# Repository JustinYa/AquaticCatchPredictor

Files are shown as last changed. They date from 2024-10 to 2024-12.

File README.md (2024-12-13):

# Abstract

AquaticCatchPredictor is a predictive system designed to enhance fishing efficiency by leveraging environmental data and machine learning. It analyzes key factors such as temperature, pressure, water activity, and geographic location to determine the best fishing spots and predict fish activity. The system integrates real-time weather data and decision tree models to provide actionable insights, helping anglers make informed decisions. Its user-centric design focuses on accuracy, usability, and adaptability to diverse aquatic environments.

# Team

* Zixuan Yang

# Required Submissions  

* [Website](https://justinya.github.io/AquaticCatchPredictor/)
* [Proposal](https://github.com/JustinYa/AquaticCatchPredictor/blob/main/docs/proposal.md)
* [Midterm Checkpoint Presentation Slides](https://github.com/JustinYa/AquaticCatchPredictor/blob/main/docs/midtermPresentation.pdf)
* [Final Presentation Slides](https://docs.google.com/presentation/d/1H-CBQTqb1kGFo9P-xzhdKyaAK2egp4QP/edit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)
* [Final Report](https://github.com/JustinYa/AquaticCatchPredictor/blob/main/docs/report.md)
* [Prediction Mode Demo Video](https://drive.google.com/file/d/1JTeIy1hggbkSafa4Nath8DWK5p9Q1THv/view?usp=sharing)
* [Location Suggestion & Navigation Modes Demo Video](https://drive.google.com/file/d/1JZ9xc8-V4VDqHVV1dyS5ZUOEnqnyqMGk/view?usp=sharing)

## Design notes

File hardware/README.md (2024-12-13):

# Hardware Folder

This folder contains all the hardware-related files for the **Fishing Prediction System**. The files include PCB layouts, electrical schematics, and 3D models for both the central and peripheral device enclosures.

## Contents

### 1. **PCB Layout**
- **`PCB_layout.pdf`**:  
  This file contains the PCB layout used to connect the electronic modules of the central device. It serves as the foundation for integrating all components within the system.

### 2. **Electrical Schematic**
- **`SCH_Schematic.pdf`**:  
  This file provides the complete electrical schematic for the system. It details all the connections between the components, ensuring accurate assembly of the electronic modules.

### 3. **3D Models**
The folder includes `.stl` files for the enclosures of the central and peripheral devices, as well as demo files representing fully assembled devices:

#### Central Device:
- **`centralA.stl`** and **`centralB.stl`**:  
  These are the 3D models for the **enclosure of the central device**.
- **`central_device_demo.stl`**:  
  This file represents the **fully assembled central device**, showcasing how the components fit together.

#### Peripheral Device:
- **`peripheralA.stl`** and **`peripheralB.stl`**:  
  These are the 3D models for the **enclosure of the peripheral device**.
- **`peripheral_demo.stl`**:  
  This file represents the **fully assembled peripheral device**, providing a complete view of the final design.

## Usage Instructions
1. **PCB Layout**:  
   Use `PCB_layout.pdf` as a reference for creating the circuit board to connect the central device's electronic modules.
2. **Electrical Schematic**:  
   Refer to `SCH_Schematic.pdf` to ensure all components are correctly connected during assembly.
3. **3D Models**:  
   - Load the `.stl` files into a 3D modeling or printing tool to visualize or manufacture the enclosures.  
   - Use the `*_demo.stl` files to understand the final appearance of the fully assembled devices.

## Notes
- The `PCB_layout.pdf` and `SCH_Schematic.pdf` files are crucial for ensuring proper hardware functionality.  
- The `.stl` files allow you to fabricate the physical enclosures for the devices and understand the assembly process.

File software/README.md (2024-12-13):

# Software Folder

This folder contains all the necessary software files for the **Fishing Prediction System**. It includes Arduino IDE sketches for the central and peripheral devices, as well as a Python script for training the decision tree model.

## Contents

### 1. **Arduino Files**
These `.ino` files are used to program the central and peripheral devices using the **Arduino IDE**:
- **`ble_central.ino`**:  
  The code for the **central device**, handling data collection, Bluetooth communication, and predictions using pre-trained models.
- **`ble_peripheral.ino`**:  
  The code for the **peripheral device**, responsible for gathering environmental data (temperature, pressure, etc.) and transmitting it to the central device via Bluetooth.

### 2. **Python Script**
- **`decision_tree_training.ipynb`**:  
  This Python notebook is used to train the **decision tree model**. It processes collected data, trains the model, and exports the decision tree rules for integration into the Arduino sketches.

## Usage Instructions
1. **Arduino Sketches**:  
   - Open `ble_central.ino` and `ble_peripheral.ino` in the Arduino IDE.
   - Upload the respective code to the central and peripheral devices to enable system functionality.
2. **Python Script**:  
   - Run `decision_tree_training.ipynb` in a Jupyter Notebook environment to train the decision tree model.
   - Export the trained model logic and incorporate it into the central device's Arduino code for predictions.

## Notes
- Ensure all required libraries for Arduino IDE are installed before uploading the sketches.
- The Python script requires standard machine learning libraries like `scikit-learn` for training the decision tree model.

For further assistance, refer to the main repository README or contact the project team.

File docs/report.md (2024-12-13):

# Table of Contents
* Abstract
* [Introduction](#1-introduction)
* [Related Work](#2-related-work)
* [Technical Approach](#3-technical-approach)
* [Evaluation and Results](#4-evaluation-and-results)
* [Discussion and Conclusions](#5-discussion-and-conclusions)
* [Demo Links](#6-demo-links)
* [References](#7-references)

# Abstract

The AquaticCatchPredictor project utilizes Machine Learning techniques to analyze fishing data, including GPS location, temperature, air pressure, and water activity. By collecting real-time environmental data, the system predicts catch rates under current fishing conditions and provides on-site recommendations to enhance fishing success. This approach aims to assist anglers in making informed decisions based on environmental factors, thereby improving their catch rates. The integration of machine learning ensures that predictions adapt to varying conditions, making the AquaticCatchPredictor a valuable tool for recreational and professional fishing alike.

# 1. Introduction

# 1. Introduction

## 1.1. Motivation & Objective

Fishing can be an enjoyable and rewarding activity, but it is not without its frustrations. One memorable experience involved using a fishing app that predicted excellent fish activity, prompting a fishing trip with friends. Unfortunately, not a single fish was caught that day, which highlighted the limitations of existing fishing prediction tools. This experience inspired the idea for a more reliable and data-driven solution. Both recreational and competitive anglers could benefit from such a system, as it would help them save time, reduce wasted effort, and improve their overall fishing success.

The primary objective of this project is to develop a portable device that predicts fish activity and recommends optimal fishing spots. This device will integrate environmental data such as temperature, pressure, and weather conditions to analyze fish behavior effectively. Additionally, the system will provide real-time insights using GPS and live weather updates, ensuring anglers have the most accurate information. By incorporating decision tree algorithms, this solution will improve prediction accuracy, reduce uncertainty, and create a more effective fishing experience.

## 1.2. State of the Art & Its Limitations

Currently available fishing apps rely heavily on general weather data and historical trends to provide predictions. While these tools offer a basic level of assistance, they have several limitations. For example, they often lack real-time data integration, which makes it challenging to adapt to changing environmental conditions. Additionally, these apps do not provide location-specific accuracy, which is crucial for anglers seeking reliable predictions for specific fishing spots. Personalized recommendations based on individual preferences or fishing goals are also absent in most existing solutions.

These limitations lead to inconsistent performance, which diminishes user trust and effectiveness. This project aims to address these shortcomings by providing a data-driven, accurate, and personalized solution tailored to the unique needs of anglers.

## 1.3. Novelty & Rationale

This project offers several unique features that set it apart from current fishing prediction tools. First, the predictions are based on scientifically collected data, ensuring high reliability and accuracy. The device also includes offline functionality, enabling it to operate independently of internet access by utilizing onboard sensors and pre-trained models. Furthermore, decision tree algorithms are employed to deliver precise predictions about fish activity, providing a significant improvement over generalized or heuristic approaches. These innovations make the system an effective tool for improving fishing outcomes in diverse conditions.

## 1.4. Potential Impact

This fishing prediction system provides anglers with accurate, location-specific insights, improving catch rates and reducing wasted effort. For competitive anglers, it offers a strategic advantage through real-time data and decision tree algorithms. Its offline functionality enables use in remote areas, while promoting sustainable fishing by minimizing environmental impact. With strong potential for commercial applications, the system addresses key gaps in current fishing technologies and enhances the overall fishing experience.

## 1.5. Challenges

Collecting a robust and comprehensive dataset for training the model within the constraints of limited time and resources is a significant challenge. To ensure the model's accuracy and generalizability, the dataset must include diverse fishing scenarios, incorporating varying skill levels of anglers, from beginners to experts. Additionally, it is essential to gather data from multiple locations within the same waterbody, covering a wide range of environmental conditions such as temperature, pressure, and water activity. These variations are critical for capturing the complex factors that influence fish behavior. Achieving this level of diversity in data collection requires extensive planning, coordination, and effort, making it one of the most demanding aspects of the project.

## 1.6. Required Skills and Resources

Successfully completing this project requires a combination of skills and hardware resources:

### Skills
- **Sensor Integration**: Proficiency in working with sensors such as thermometers, barometers, and IMUs to collect accurate environmental data.
- **Bluetooth Communication**: Knowledge of Bluetooth protocols to enable seamless data transfer between devices.
- **Microcontroller Programming**: Familiarity with embedded system programming, particularly for configuring and managing microcontroller operations.
- **PCB Design**: Experience in designing and fabricating printed circuit boards (PCBs) to integrate system components efficiently.
- **3D Modeling**: Ability to create 3D models for designing and manufacturing the device’s enclosure, ensuring durability and ergonomic design.

### Hardware Resources
- **ESP32**: A versatile microcontroller for managing system operations and communication.
- **Arduino Nano 33 BLE**: For low-power processing and Bluetooth communication.
- **0.97-inch OLED Display**: For displaying real-time predictions and system status.
- **Neo-6M GPS Module**: For obtaining accurate location data to improve fishing predictions.

## 1.7. Metrics of Success

The success of the fishing prediction system is evaluated using a combination of accuracy, performance, and efficiency metrics. Prediction accuracy is assessed through Mean Squared Error (MSE), which calculates the average squared difference between predicted and actual values, and Root Mean Squared Error (RMSE), which provides an interpretable error measure in the same units as the target variable. To analyze model performance, Relative Error is used to measure the difference between testing and training MSE as a percentage of the training MSE, highlighting potential overfitting or underfitting. Prediction speed is another key metric, focusing on the time required for the system to compute a prediction, which is critical for real-time applications. Additionally, power efficiency is evaluated by measuring average power consumption in milliwatts (mW) and estimating battery life in hours based on the available power source. These metrics collectively ensure the system's accuracy, responsiveness, and practicality in real-world scenarios.

# 2. Related Work

Fishing apps are widely available on the market and are popular among anglers for their ability to predict fish activity. These apps typically gather environmental data such as temperature, barometric pressure, and wind speed through internet-based weather services. By combining this information with basic fishing heuristics—such as how weather conditions influence fish behavior—they aim to provide users with insights into the best times and locations to fish. However, the reliance on simplistic rules rather than advanced data-driven algorithms often results in limited prediction accuracy and adaptability, particularly in dynamic or less-studied fishing environments.

Most of these applications are designed for use on smartphones, leveraging their convenience and portability. However, they are heavily dependent on an active internet connection to fetch real-time data. This reliance introduces a significant limitation: in remote locations where internet access is unavailable or unreliable, these apps become unusable. Such scenarios are common in rural or wilderness fishing spots, leaving anglers without reliable tools to guide their efforts.

This project seeks to address these limitations by designing a fully offline solution that does not rely on internet connectivity. Instead, it integrates onboard sensors to collect local environmental data and employs advanced machine learning algorithms to provide accurate predictions. By eliminating the need for external data sources, this system ensures functionality in remote areas while offering a higher degree of reliability and precision compared to existing fishing apps. This offline capability not only enhances usability but also makes the system a more practical and versatile tool for anglers in diverse environments.

# 3. Technical Approach

## 3.1. System Architecture

The system is designed with a modular architecture comprising two main components: a peripheral device and a central device. Each component has distinct responsibilities that work in tandem to collect, process, and deliver fishing predictions. The two devices communicate wirelessly via Bluetooth, ensuring efficient data transfer and seamless functionality in real-time.

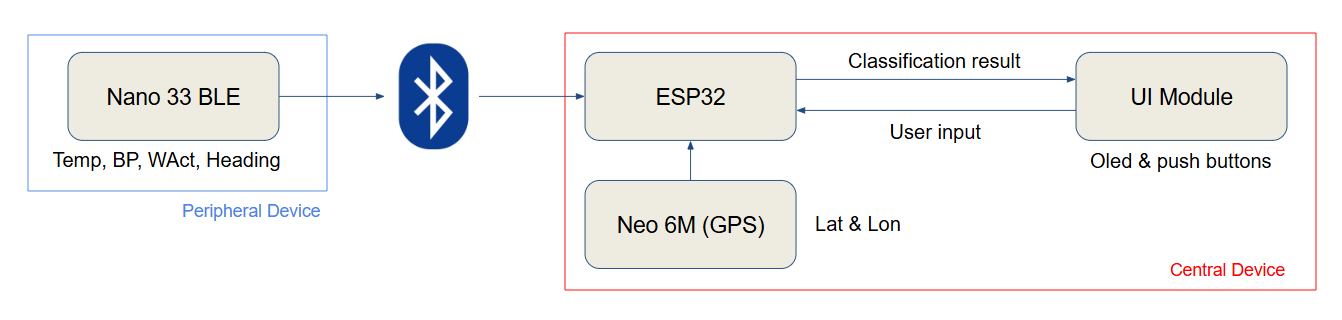
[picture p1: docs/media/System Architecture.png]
System Architecture


The **peripheral device** is built around the Arduino Nano 33 BLE, chosen for its low power consumption and integrated Bluetooth capabilities. Powered by a 500mAh LiPo battery, it is equipped with several onboard sensors to capture environmental data. These include:
- **Water Temperature Sensor**: Measures the temperature of the water.
- **Barometric Pressure Sensor**: Records atmospheric pressure for weather analysis.
- **Inertial Measurement Unit (IMU)**: Detects water surface activity based on motion data.
- **Magnetometer**: Monitors orientation to account for device positioning.

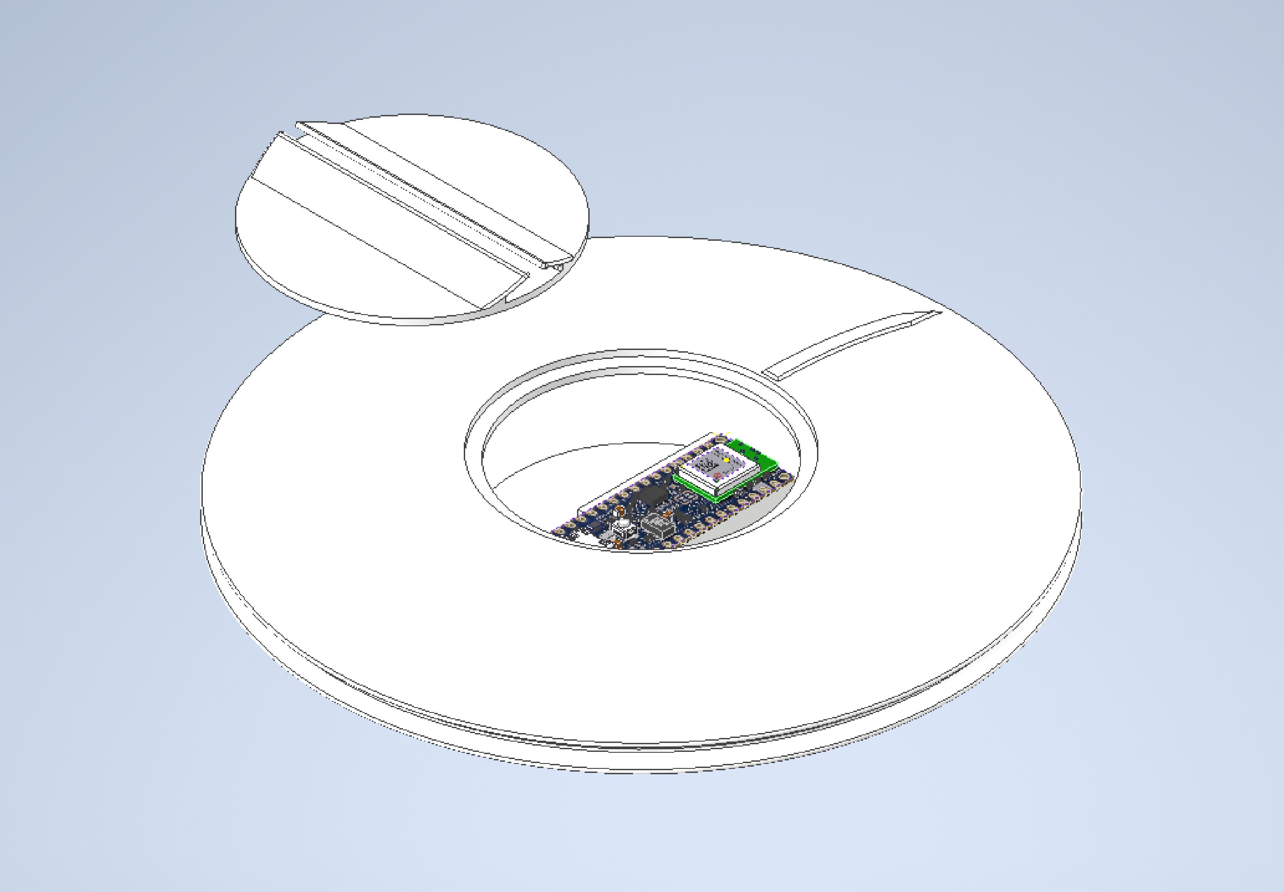
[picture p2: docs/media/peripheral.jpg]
Peripheral Device


The peripheral device collects these data points and transmits them wirelessly to the central device, ensuring that the system can operate effectively even in remote locations.

The **central device**, powered by an ESP32 microcontroller, is the computational hub of the system. It processes the data received from the peripheral device and generates fishing predictions using pre-trained machine learning models. The central device is equipped with:
- A **Neo-6M GPS Module** for obtaining precise location data, critical for tailoring predictions to specific fishing spots.
- An **OLED Display** for presenting fishing recommendations and system status to the user.
- **Push Buttons** to allow for user interaction, such as inputting preferences or navigating the interface.
- A **500mAh LiPo Battery**, providing sufficient power for extended use in outdoor environments.

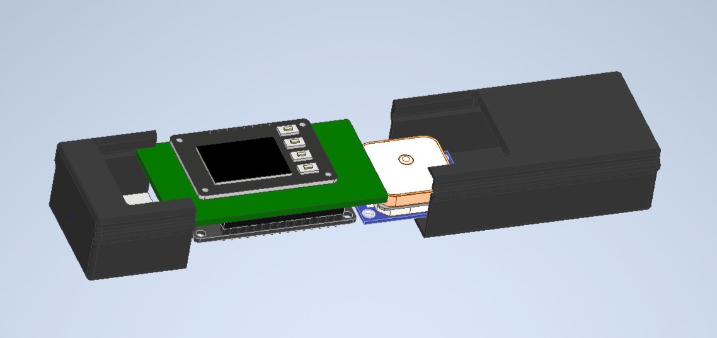
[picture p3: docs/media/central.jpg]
Central Device
 

The communication between the peripheral and central devices relies on Bluetooth, ensuring fast and reliable data transfer without the need for internet connectivity. This modular design allows for flexibility and scalability, with the peripheral device specializing in data collection and the central device handling computation and user interaction. By separating these roles, the system achieves higher efficiency and adaptability, making it suitable for various fishing scenarios and environments.

## 3.2. Data Collection

The data collection process was designed to ensure a comprehensive dataset by incorporating variations in fishing skill levels, locations, environmental conditions, and weather patterns.

### Participants
Three participants with varying fishing expertise—beginner, intermediate, and expert—were selected to contribute to the dataset. This diversity ensures that the collected data reflects a wide range of fishing behaviors and skill levels, which is crucial for building a robust prediction model.

### Locations
Data was collected simultaneously at three distinct spots within the same waterbody. Peripheral devices were connected to the nRF App on smartphones for real-time logging. These spots were chosen to capture diverse environmental conditions, enhancing the dataset’s representativeness.

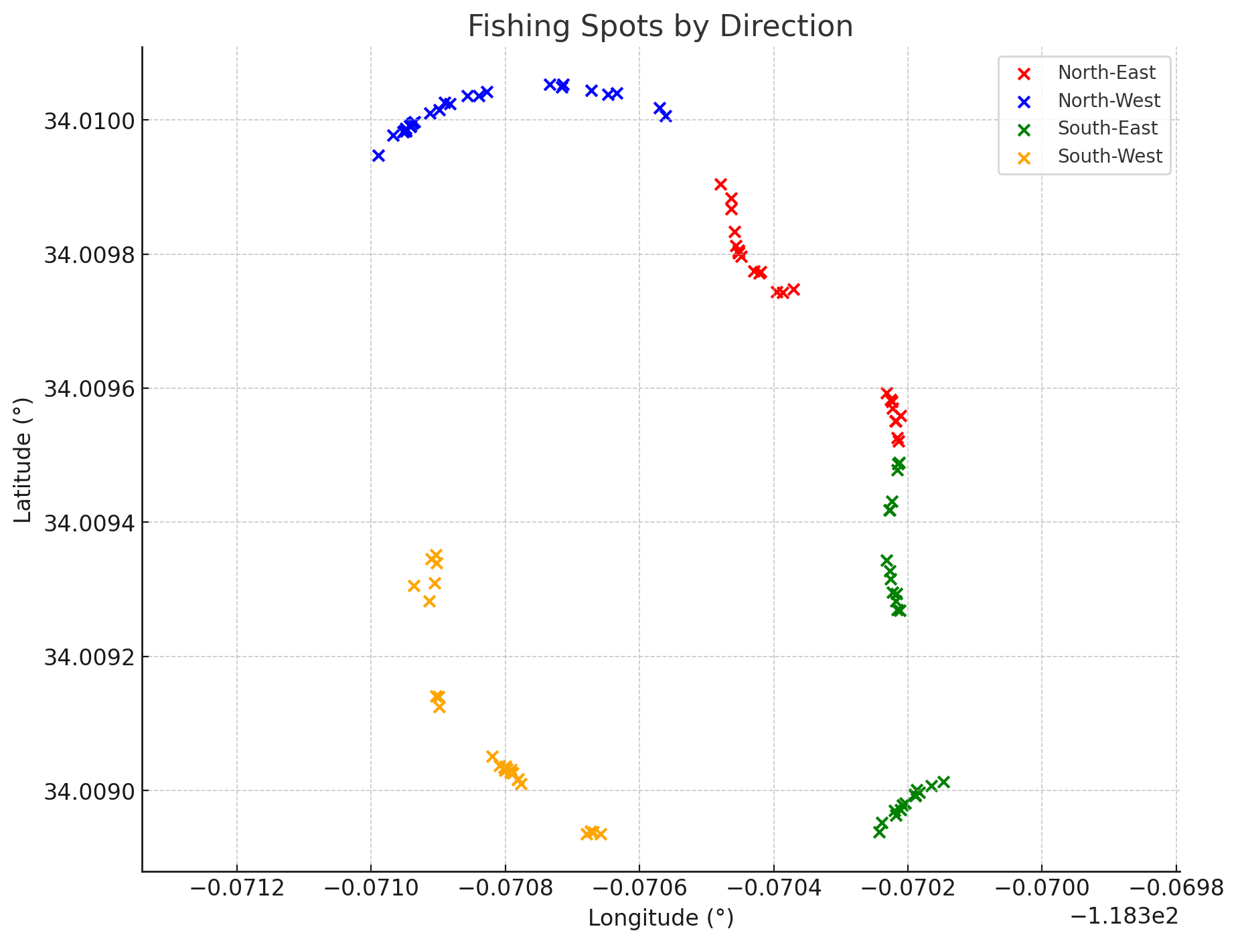
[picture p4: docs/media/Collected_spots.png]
Collected Spots


### Process
Each data collection session lasted 30 minutes, with participants rotating between the three locations every 10 minutes. This rotation ensured that each location included data from all three participants, thereby improving the objectivity and reliability of the dataset. Efforts were made to cover the entire lake during data collection, but certain areas, such as the North-West section, were inaccessible due to obstructions like reeds.

### Duration
Data collection was conducted over six days, with three hours of collection each day. The weather conditions during these six days were carefully distributed: two days were categorized as hot, two as cold, and two as moderate. This distribution allowed the dataset to capture the influence of varying weather conditions on fish behavior. Each day yielded 18 individual data entries, resulting in a total of 108 data points for the entire experiment.

The structured process of data collection, combined with diverse participant expertise, strategically chosen locations, and a variety of weather conditions, ensures that the dataset is comprehensive, reliable, and suitable for training the fishing prediction model.

## 3.3. Data Processing

The data collected during the experiment was processed to create a structured and reliable dataset for analysis and model training. Data from the nRF App was exported and consolidated into an Excel spreadsheet, including variables such as date, latitude, longitude, temperature, pressure, water activity, bite rate, and fishing spot location. The bite rate, calculated by summing the catches from all three participants at each location during a 30-minute session, served as the key target variable for the model. This approach ensured a comprehensive measure of fish activity, accounting for variations in skill levels and environmental conditions. The dataset was thoroughly reviewed for quality, with no missing values identified. However, minor GPS shifts were observed and manually adjusted to maintain accuracy. These steps ensured the dataset's readiness for machine learning applications, forming a solid foundation for reliable fishing predictions.

## 3.4. Model Training

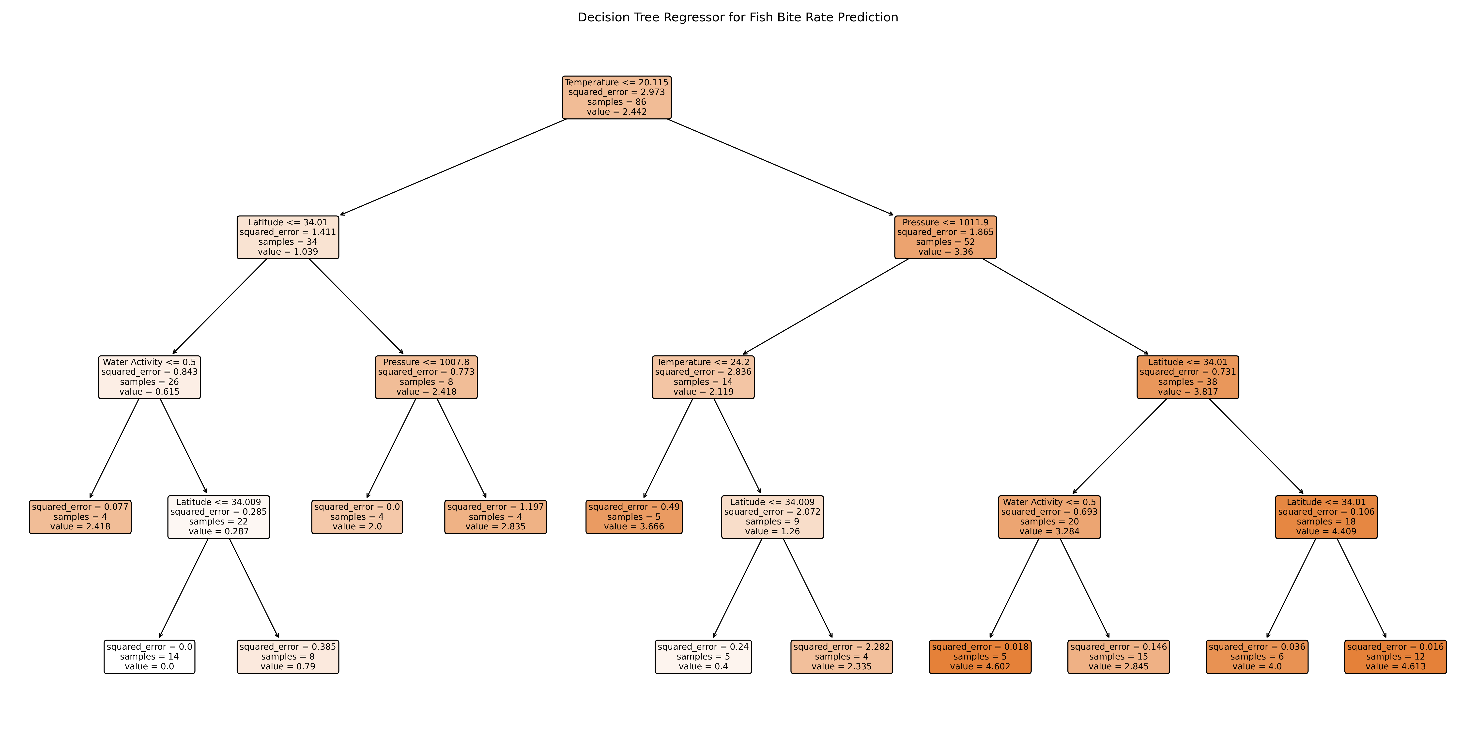
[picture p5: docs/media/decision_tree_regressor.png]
Decision Tree


The prediction model was built using a decision tree regressor implemented in Python. The input features included environmental variables such as temperature, pressure, water surface activity, and geographical location. These variables were selected for their direct impact on fish behavior and bite rates. The dataset was split into training and testing sets using an 80/20 ratio to ensure a balanced evaluation of the model’s performance. The decision tree algorithm was chosen for its interpretability and ability to handle non-linear relationships within the data. 

## 3.5. Model Tuning

During initial training, the decision tree model exhibited signs of overfitting, with the training Mean Squared Error (MSE) being significantly lower than the testing MSE. To address this issue, parameters such as the maximum depth of the tree and the minimum number of samples required at a leaf node were introduced to constrain the model's complexity. The best performance was achieved with a maximum depth of 4 and a minimum of 4 samples per leaf, which balanced the trade-off between accuracy and generalization. This tuning step ensured that the model could make reliable predictions without overfitting to the training data.

# 4. Evaluation and Results

## 4.1. Results

The performance of the fishing prediction system was evaluated across multiple dimensions, including prediction accuracy, processing speed, and power efficiency. These evaluations reflect the system’s suitability for real-world fishing applications and its ability to operate under various constraints.

### Prediction Accuracy
The decision tree model demonstrated reliable predictive performance, achieving the following metrics:
- **Testing MSE**: 0.2498  
- **Training MSE**: 0.2751  
- **Testing RMSE**: 0.4998  
- **Training RMSE**: 0.5245  
- **Relative Error**: 10.12% (difference between Training MSE and Testing MSE)

Model Accuracy Results

The small difference between training and testing MSE indicates that the model has effectively avoided overfitting, maintaining good generalization across unseen data. The RMSE values further provide an interpretable measure of error in the same units as the target variable, confirming the model's accuracy for predicting fish bite rates.

### Feature Importance

The feature importance analysis reveals that **Temperature** is the most significant factor, with an importance score of **0.56**, indicating its dominant role in the model's predictions. Other features like **Latitude** (**0.19**), **Pressure** (**0.13**), and **Water Activity** (**0.12**) also contribute meaningfully, while **Longitude** (**0.00**) has no observable impact. These results suggest that the model is primarily driven by temperature variations, with secondary influences from location and pressure metrics.

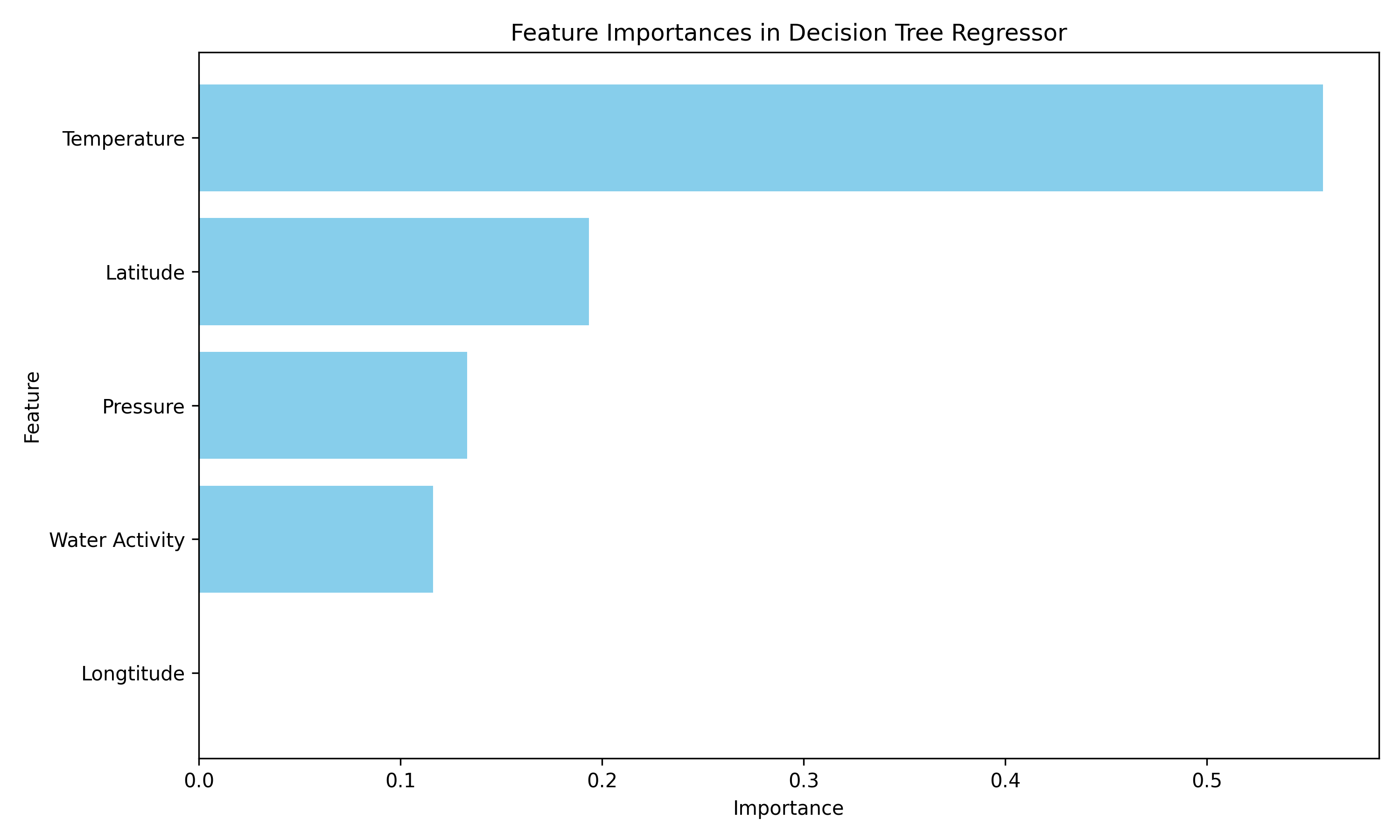
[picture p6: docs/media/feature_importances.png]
Feature Importances


### Processing Speed
The system achieved an average prediction speed of **15 ms** per query, enabling near-instantaneous feedback for users in real-time fishing scenarios. This rapid response ensures that anglers can make timely decisions based on current environmental conditions.

### Power Efficiency
The power efficiency of the system was analyzed for both the central and peripheral devices:

#### Central Device
- **Average Power Consumption**: 408.6 mW  
- **Battery Life**: Approximately 4.77 hours on a 500mAh battery  
- **Memory Usage**: 90%

The central device’s higher power consumption is attributed to its computational workload, which includes processing data, running machine learning models, and managing the user interface. Despite this, the device maintains sufficient battery life for typical fishing trips.

#### Peripheral Device
- **Average Power Consumption**: 70.2 mW  
- **Battery Life**: Approximately 27.76 hours on a 500mAh battery  
- **Memory Usage**: 23%

The peripheral device’s low power consumption and memory usage highlight its role as a dedicated data collection unit, with an extended battery life that ensures uninterrupted operation during long fishing sessions. Combined with the central device’s efficient power management and high computational capability, the results demonstrate a well-balanced system that excels in prediction accuracy, responsiveness, and energy efficiency. The low relative error confirms the reliability and generalization of the model, while the fast prediction speed makes it practical for real-time use. These features collectively ensure prolonged usability in outdoor environments, even under limited power availability, making the system a robust and effective tool for enhancing the fishing experience for both recreational and professional anglers.

## 4.2. Findings

A user study involving five participants provided valuable insights into how the fishing prediction system was used by different groups and its effectiveness under real-world conditions. 

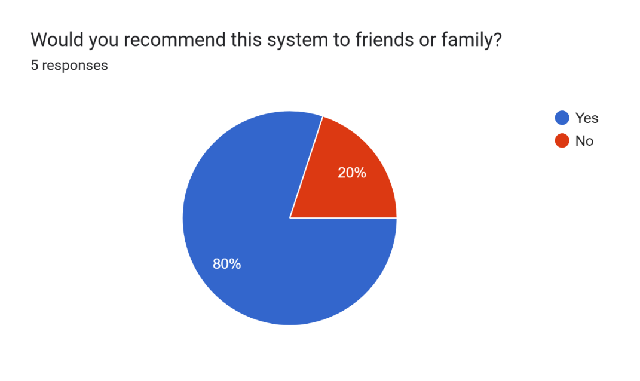
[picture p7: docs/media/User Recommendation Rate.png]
User Recommendation Feedback


### Beginners 
Beginners exhibited a high level of dependence on the system, using it more frequently to guide their fishing efforts. They primarily relied on the system's location recommendations to identify optimal fishing spots, particularly when navigating unfamiliar environments. Despite this reliance, their actual catch rates were generally lower than the system's predictions. This discrepancy can be attributed to two main factors: the participants' lack of fishing experience and the limitations of the training dataset. During data collection, the dataset did not include data from individuals with no fishing experience, leading to a slight mismatch between the model's predictions and the performance of completely inexperienced users. For this group, the system acted as a critical tool to improve their understanding of fishing conditions and strategies, even if their results initially fell short of predictions. 

To address this limitation in the future, a potential improvement could involve adding a **rating functionality** to the system. Users could self-assess and input their fishing skill level, allowing the system to appropriately scale its predictions based on their experience. This feature would enable more personalized and accurate recommendations for users of all skill levels.

### Intermediate and Advanced Users
Intermediate and advanced users demonstrated a different usage pattern, interacting with the system less frequently compared to beginners. These participants showed a high alignment between their actual catch rates and the system's predictions, reflecting their ability to effectively combine personal experience with system insights. For this group, the fish activity predictions were particularly valuable, as they used the system to refine their fishing strategies rather than as a primary guide. The system served as a supplementary tool to enhance their fishing efficiency and decision-making.

The study highlighted the system's ability to cater to a wide range of users. Beginners benefited most from the location recommendations, using the system to gain confidence and improve their results. In contrast, more experienced anglers used the system to enhance their existing skills, demonstrating its adaptability and effectiveness across skill levels. These findings underscore the system’s potential as both a learning aid and a strategic tool for diverse fishing scenarios, with opportunities for future enhancements such as skill-based scaling to improve its accuracy and usability.

# 5. Discussion and Conclusions

## Discussion

### Hardware Improvements
The system’s hardware components are functional but present opportunities for improvement. Replacing the current GPS module with an Adafruit GPS module could lower power consumption and support low-power modes, extending battery life for prolonged use. Additionally, optimizing the device enclosure to make it more compact and portable would enhance user convenience, especially for outdoor activities.

### Data Collection
Expanding the scope of data collection to include more sessions and diverse water bodies would significantly improve the model's accuracy and generalizability. Incorporating data from a wider range of environmental conditions and user experiences, including completely inexperienced anglers, could help address current limitations and refine the system’s predictions.

### Future Features
Future iterations of the system could include additional measurements such as water depth and dissolved oxygen to improve prediction accuracy. Furthermore, integrating a user rating feature would allow individuals to specify their skill level. This feature would enable the system to scale predictions accordingly, providing personalized recommendations tailored to each user’s expertise.

## Conclusions
The fishing prediction system successfully helps both beginners and experienced anglers by providing actionable fishing predictions. Beginners benefit most from location recommendations, frequently using the system as a guide to navigate unfamiliar conditions. Experienced users rely more on fish activity predictions to refine their strategies, using the system as a supplementary tool. 

The decision tree model performs well, achieving low testing errors and accurate predictions under diverse conditions. The system’s real-time prediction capability and low power consumption make it a reliable choice for extended fishing trips. User feedback underscores the system’s value, with 80% of participants expressing a willingness to recommend it to others.

Overall, the system demonstrates its potential to enhance the fishing experience for a wide range of users, while the proposed improvements and features highlight opportunities to further increase its effectiveness and user satisfaction.

# 6. Demo Links

* [Prediction Mode Demo Video](https://drive.google.com/file/d/1JTeIy1hggbkSafa4Nath8DWK5p9Q1THv/view?usp=sharing)
* [Location Suggestion & Navigation Modes Demo Video](https://drive.google.com/file/d/1JZ9xc8-V4VDqHVV1dyS5ZUOEnqnyqMGk/view?usp=sharing)

# 7. References

1. M. Iiyama, K. Zhao, A. Hashimoto, H. Kasahara, and M. Minoh, “Fishing spot prediction by sea temperature pattern learning,” *2018 OCEANS - MTS/IEEE Kobe Techno-Oceans (OTO)*, pp. 1–4, May 2018. doi: [10.1109/oceanskobe.2018.8559299](https://doi.org/10.1109/oceanskobe.2018.8559299)

2. M.-T. Thai, T.-N. Chu-Ha, T.-A. Vo, and T.-H. Do, “An approach to recommend fishing location and forecast fish production by using Big Data Analysis and distributed deep learning,” *2022 RIVF International Conference on Computing and Communication Technologies (RIVF)*, pp. 322–327, Dec. 2022. doi: [10.1109/rivf55975.2022.10013876](https://doi.org/10.1109/rivf55975.2022.10013876)

3. Gauravduttakiit, “Hyperparameter tuning in decision trees,” *Kaggle*, [https://www.kaggle.com/code/gauravduttakiit/hyperparameter-tuning-in-decision-trees](https://www.kaggle.com/code/gauravduttakiit/hyperparameter-tuning-in-decision-trees) (accessed Dec. 12, 2024).

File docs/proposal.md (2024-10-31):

# Proposal for Portable Fishing Prediction System

---

### 1. Motivation & Objective
The primary goal of this project is to increase fishing efficiency by providing anglers with a real-time fishing index based on various environmental factors, including temperature, barometric pressure, water activity, and GPS location. By analyzing these parameters on-site, the system aims to offer more accurate fishing predictions than generic weather-based solutions, ultimately enhancing the fishing experience and success rate.

---

### 2. State of the Art & Its Limitations
Currently, most fishing prediction systems are based on empirical knowledge and some known environmental factors rather than scientific analysis derived from actual data. These systems often fail to accurately capture the specific conditions of the fishing site, such as real-time water activity and localized weather patterns, which can significantly influence fish behavior. Additionally, traditional fishing apps depend on cloud services for data processing and prediction, which presents several limitations. First, they require a stable internet connection, making them unreliable in remote fishing locations with poor or no signal. Second, relying on cloud processing drains phone battery life quickly, which limits usability during extended fishing trips. In contrast, an on-device, low-power sensor system can continuously monitor environmental factors specific to the fishing location. This approach is not only more energy-efficient but also works offline, enhancing both longevity and privacy.

---

### 3. Novelty & Rationale
This project introduces several novel elements to fishing prediction. First, by using localized, real-time data, the system relies on actual data from the fishing site, such as water movement detected by an accelerometer, along with temperature, pressure, and location, to provide a comprehensive fishing index. Second, the system supports offline capability. By utilizing pre-trained machine learning models, it processes data locally, eliminating the need for cloud-based computations and enabling functionality in remote fishing locations without cellular connectivity. Additionally, for pattern recognition, the device uses decision trees or SVM (Support Vector Machines) to analyze patterns from the collected data, allowing it to dynamically identify optimal fishing conditions without requiring constant internet access. Furthermore, this system could be beneficial in competitive fishing events like Bassmaster, where it provides insights into fish activity patterns in specific water areas. By offering data-driven analyses, it has the potential to increase the event's appeal to audiences. This combination of real-time, location-specific analysis with energy-efficient, offline operation sets the device apart from conventional fishing prediction systems.

---

### 4. Potential Impact
The successful implementation of this project could have a significant impact on recreational and competitive fishing. By offering more accurate, real-time predictions, anglers can make informed decisions about where and when to fish, improving their success rate and overall satisfaction. Additionally, with better data on fish activity, anglers can target specific times for fishing, potentially reducing overfishing and promoting sustainable practices. Furthermore, this project demonstrates the potential of TinyML and low-power sensor fusion in outdoor, real-time applications, encouraging further development in portable IoT solutions.

---

### 5. Challenges
This project faces several challenges. First, unlike weather forecasting, fishing prediction requires specific environmental and behavioral data for different fishing locations and times. There is no existing comprehensive database, necessitating the collection of real-world data across various conditions. Second, to ensure the data accurately represents different fishing environments, input is needed from anglers of varied experience levels in multiple geographic and environmental settings. This diversity is crucial to train a model that generalizes well across conditions.

---

### 6. Requirements for Success
The success of this project hinges on several technical skills and hardware components. Key technical skills include proficiency in C++ and Python programming, particularly for embedded systems development. Familiarity with machine learning, especially in model optimization for embedded devices (TinyML), is crucial for achieving efficient, on-device processing. Additionally, 3D modeling skills are needed to design a portable and ergonomic casing for the device. A basic knowledge of fishing is also beneficial for understanding and identifying relevant environmental factors that influence fish activity.

The hardware requirements for this project include a microcontroller, such as the ESP32, to act as the core processing unit. Environmental sensors, specifically for temperature and barometric pressure, will provide real-time data about the fishing conditions. A water activity sensor, like an accelerometer, is essential for detecting movements in the water that may signal fish activity. The system also requires a GPS module for precise location tracking and a portable power source, such as a rechargeable battery, to ensure the device can operate for extended periods in remote locations.

---

### 7. Metrics of Success
The effectiveness of the fishing prediction system will be evaluated through several performance metrics. Prediction accuracy is critical; the system should reliably estimate fish activity based on environmental data. High accuracy will indicate the device’s effectiveness in analyzing real-time conditions. Another important metric is user satisfaction, which will be assessed through a survey with anglers. The survey will evaluate the prediction accuracy, ease of use, and overall utility of the device in real fishing scenarios, providing valuable feedback for further improvements.

---

### 8. Execution Plan
In the **Data Collection Phase**, data will be gathered on temperature, pressure, water movement, and GPS location across various fishing sites using a custom-designed Arduino measurement device. Collaborating with anglers to collect a diverse dataset is crucial to ensure the model’s generalizability and accuracy in different fishing conditions. 

Following data collection, the **Model Training & Optimization** phase will involve training a machine learning model, such as decision trees or SVM, on the collected data to identify patterns in fish activity. Optimization techniques like quantization and pruning will be applied to reduce model size and power requirements, enabling efficient operation on embedded hardware. 

In the **Prototype Development** phase, a prototype will be built that integrates the selected sensors, microcontroller, and power supply. Testing in real-world fishing conditions will allow for refining the device’s sensitivity and accuracy. 

The **Evaluation and Refinement** phase involves multiple rounds of testing and iteration based on performance metrics, user feedback, and battery life optimization. Finally, in the **Deployment & Field Testing** phase, the finalized prototype will be field-tested with a larger user base for additional feedback and adjustments.

---

### 9. Related Work
Though resources on freshwater fishing prediction are limited, insights can be drawn from related research on ocean fishing. For example, studies such as "Fishing Spot Prediction by Sea Temperature Pattern Learning" and "An Approach to Recommend Fishing Location and Forecast Fish Production by Using Big Data Analysis and Distributed Deep Learning" provide valuable methodologies. Although these works primarily utilize data from existing databases, they offer useful experimental frameworks that can guide the approach to data collection and analysis in a freshwater context.

---

### 10. References
- M. Iiyama, K. Zhao, A. Hashimoto, H. Kasahara and M. Minoh, "Fishing Spot Prediction by Sea Temperature Pattern Learning," 2018 OCEANS - MTS/IEEE Kobe Techno-Oceans (OTO), Kobe, Japan, 2018, pp. 1-4, doi: 10.1109/OCEANSKOBE.2018.8559299. keywords: {Ocean temperature;Support vector machines;Training data;Machine learning;Boats;Temperature distribution}.

- M. -T. Thai, T. -N. Chu-Ha, T. -A. Vo and T. -H. Do, "An Approach to Recommend Fishing Location and Forecast Fish Production by Using Big Data Analysis and Distributed Deep Learning," 2022 RIVF International Conference on Computing and Communication Technologies (RIVF), Ho Chi Minh City, Vietnam, 2022, pp. 322-327, doi: 10.1109/RIVF55975.2022.10013876. keywords: {Deep learning;Costs;Time series analysis;Predictive models;Big Data;Fish;Data models;Fishing forecast;Big Data;Time Series;Recommendation System;Distributed Deep Learning}.

---

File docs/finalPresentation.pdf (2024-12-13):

# Aquatic Catch

Predictor.

## Zixuan Yang

Motivation.

### 1. Personal Inspiration:

As an avid fishing enthusiast, I encountered a frustrating experience where a fishing app predicted excellent fish activity, leading me to

invite friends for a fishing trip. Unfortunately, not a single fish was caught that day. This sparked the idea for a more reliable and data-driven

solution.

### 2. Significance:

Who cares?

Recreational and competitive anglers aiming to improve their skills and catch rates.

Why does it matter?

Saves time and resources, creating a more enjoyable and effective fishing experience.

Objectives.

Portable Device: Create a compact system capable of predicting fish activity and recommending optimal fishing spots.

Environmental Analysis: Integrate data from temperature, pressure, and weather conditions to assess fish behavior.

Real-time Insights: Use GPS and live weather updates to identify fishing spots with the highest success potential.

Enhanced Experience: Reduce uncertainty and improve catch rates through data-driven decision-making using decision trees for

prediction.

Related Work.

Existing Solutions: Current fishing apps, offer predictions based on general weather data and

historical trends.

Limitations: These apps often lack real-time data integration, location-specific accuracy, and

personalized recommendations for anglers.

Inconsistent Performance: The variability in prediction accuracy underscores the need for a more

reliable, data-driven solution tailored to individual fishing scenarios.

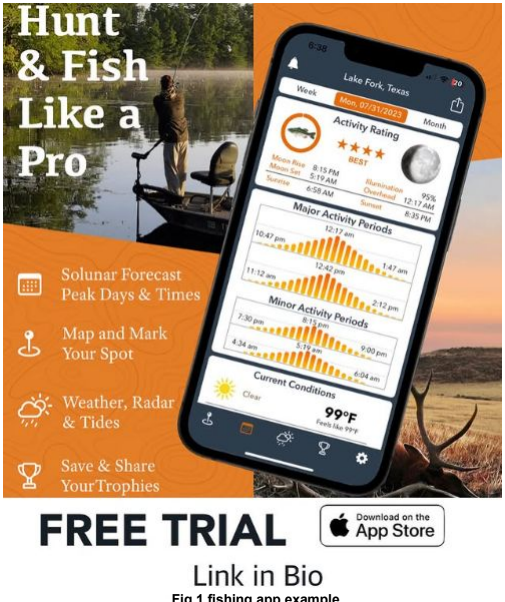
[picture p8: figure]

Fig.1 fishing app example

Novelty.

What's New:

Scientifically Collected Data: Predictions are supported by scientifically collected data, ensuring high reliability and accuracy in results.

Offline Functionality: Operates seamlessly without internet access, using onboard sensors and pre-trained models to provide predictions in

any environment.

Decision Tree Predictions: Utilizes decision tree algorithms for precise fish activity forecasts, providing a significant improvement over

generalized or heuristic methods.

Technical Approach.

The system consists of a peripheral device and a central device, optimized for specific roles:

Peripheral Device:

- Uses the Arduino Nano 33 BLE & 500mah Lipo battery with onboard sensors to collect:
- Water temperature (temperature sensor).
- Atmospheric pressure (barometric sensor).
- Water surface activity (IMU).
- Orientation (magnetometer).
- Sends data to the central device via Bluetooth.

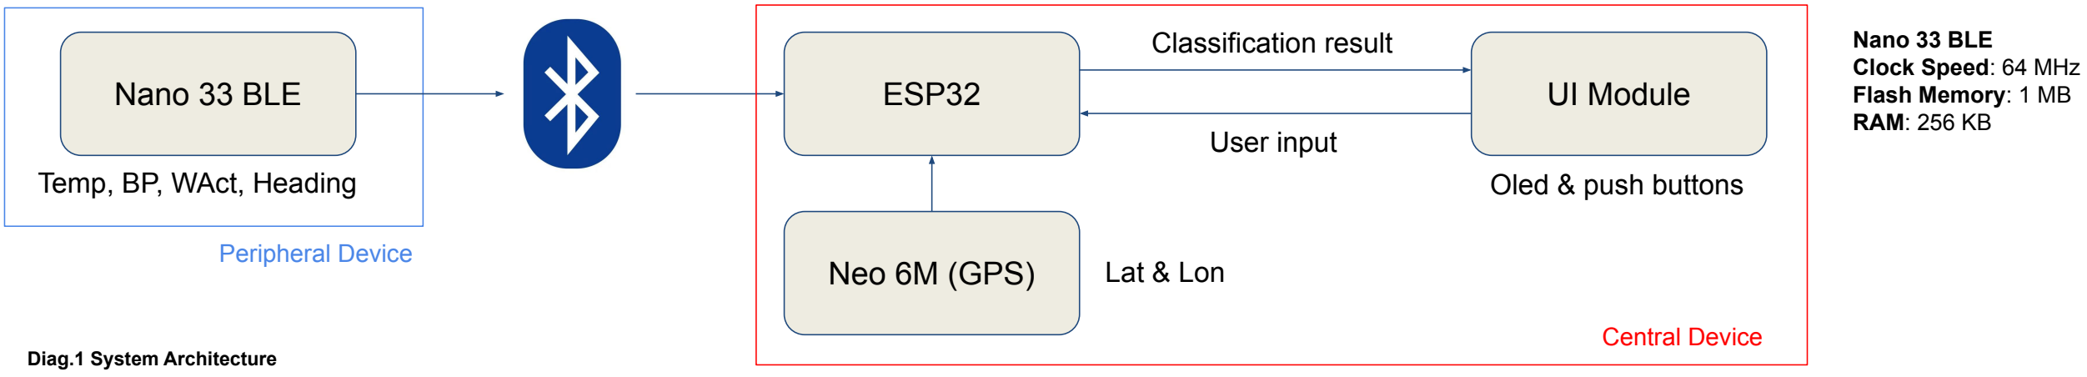
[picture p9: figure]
Nano 33 BLE; ESP32; Neo 6M (GPS); UI Module; Temp, BP, WAct, Heading; Central Device; Peripheral Device; Lat & Lon; Classification result; User input; Oled & push buttons; Diag.1 System Architecture; Nano 33 BLE Clock Speed: 64 MHz Flash Memory: 1 MB RAM: 256 KB

Technical Approach.

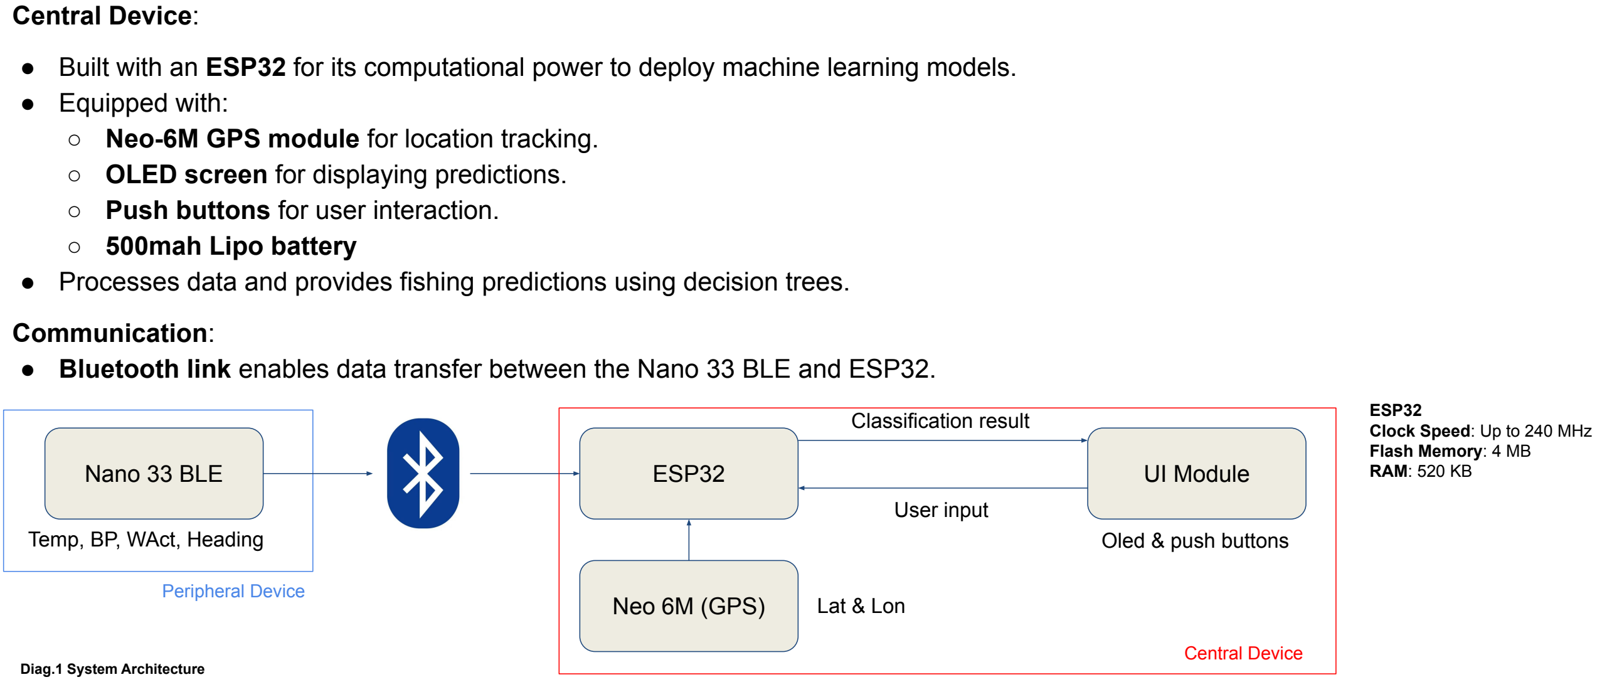
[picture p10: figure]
Neo 6M (GPS); Temp, BP, WAct, Heading; Central Device; Peripheral Device; Lat & Lon; Classification result; User input; Oled & push buttons; Central Device:; ● Equipped with:; ○ Push buttons for user interaction. ○ 500mah Lipo battery; Communication:; Diag.1 System Architecture; ESP32 Clock Speed: Up to 240 MHz

- Built with an ESP32 for its computational power to deploy machine learning models.
- Neo-6M GPS module for location tracking.
- OLED screen for displaying predictions.
- Processes data and provides fishing predictions using decision trees.
- Bluetooth link enables data transfer between the Nano 33 BLE and ESP32.
Nano 33 BLE | ESP32 UI Module | Flash Memory: 4 MB RAM: 520 KB

# Methods. data collection

Participants:

Three individuals with varying fishing skill levels: beginner, intermediate, and expert.

Locations:

Data collected simultaneously at three different spots using peripheral devices connected

to the nRF App on smartphones for logging.

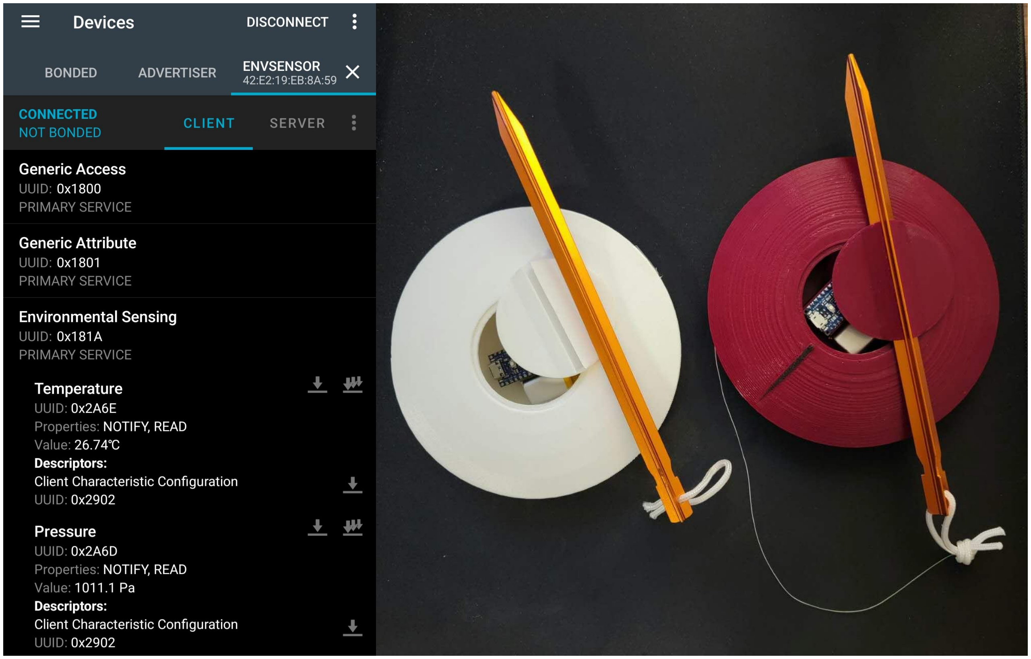
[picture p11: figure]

Fig.2 nRF App | Fig.3 Peripheral Devices (prototype_left)

# Methods. data collection

Process:

- Each session lasts 30 minutes, participants rotate between locations every 10

minutes.

- This ensures that each location has data contributed by all three participants,

enhancing the objectivity and reliability of the dataset.

- During data collection, efforts were made to cover the entire lake; however, a

section in the North-West area was obstructed by reeds, making it inaccessible for

data collection.

Duration:

- Data collected over 6 days, with 3 hours of collection each day.

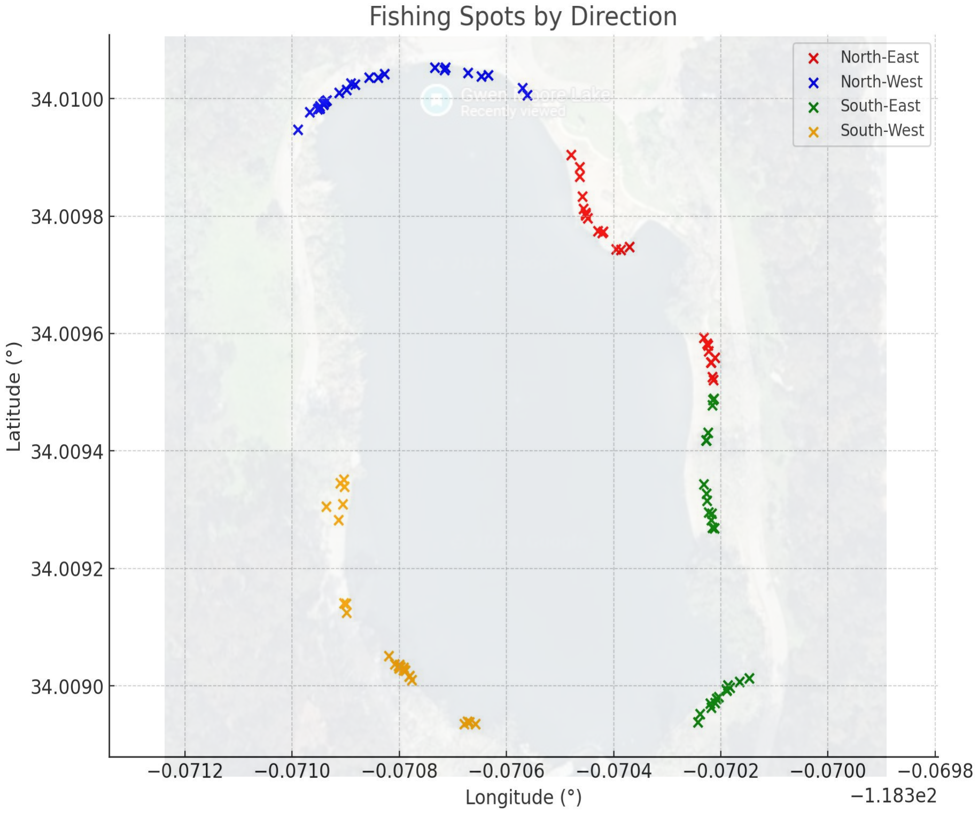
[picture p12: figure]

- Each day yields 18 data entries, totaling 108 data points across the experiment. | Fig.4 Collected Fishing Spots

# Methods. data processing

Data Aggregation:

- Collected data from the nRF App is exported and consolidated into an Excel

spreadsheet for analysis.

Bite Rate Calculation:

- Bite rate is determined by summing the catch data from all three participants at

each location during a 30-minute session.

- This provides a comprehensive measure of fish activity across skill levels at each

spot.

Data Quality:

- No missing values were identified during the data review process.
- GPS data occasionally showed slight shifts, requiring manual adjustments to

ensure accuracy.

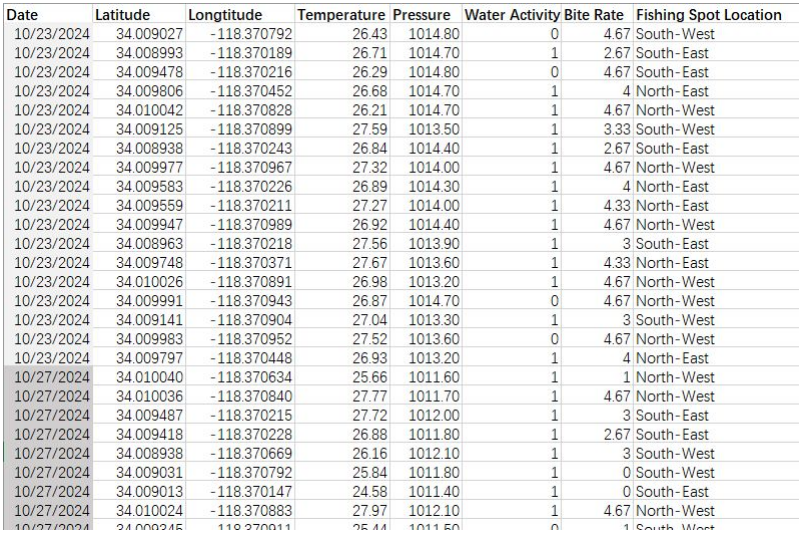
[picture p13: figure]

Fig.5 dataset

# Methods. model training

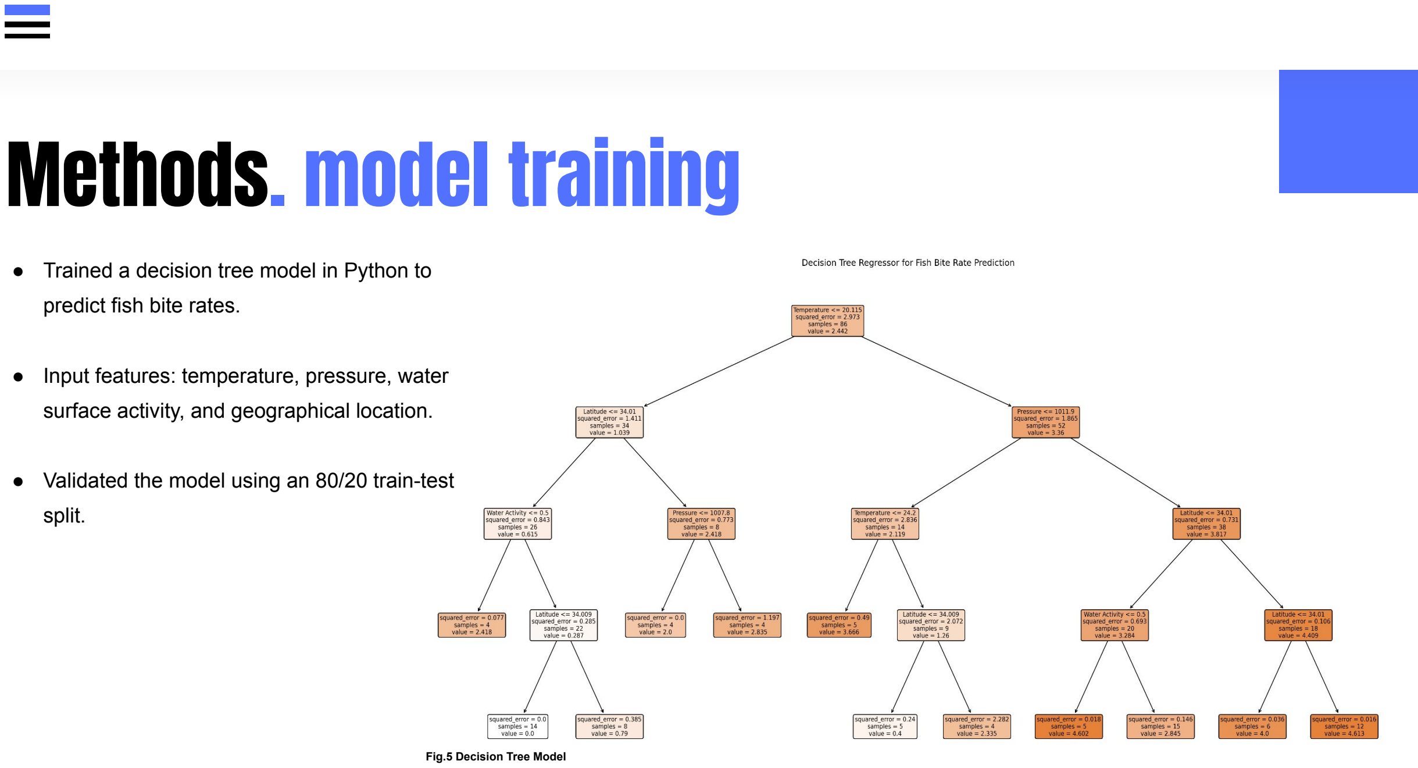
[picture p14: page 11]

- Trained a decision tree model in Python to

predict fish bite rates.

- Input features: temperature, pressure, water

surface activity, and geographical location.

- Validated the model using an 80/20 train-test

split.

Fig.5 Decision Tree Model

# Methods. model tuning

- Directly training the decision tree without constraints results in training MSE being significantly smaller than

testing MSE, indicating overfitting.

- To address this, max depth and min samples leaf parameters are introduced to limit the tree's complexity and

reduce overfitting.

- Achieved best performance with max_depth=4 and min_samples_leaf=4, balancing accuracy and

generalization.

Demo.

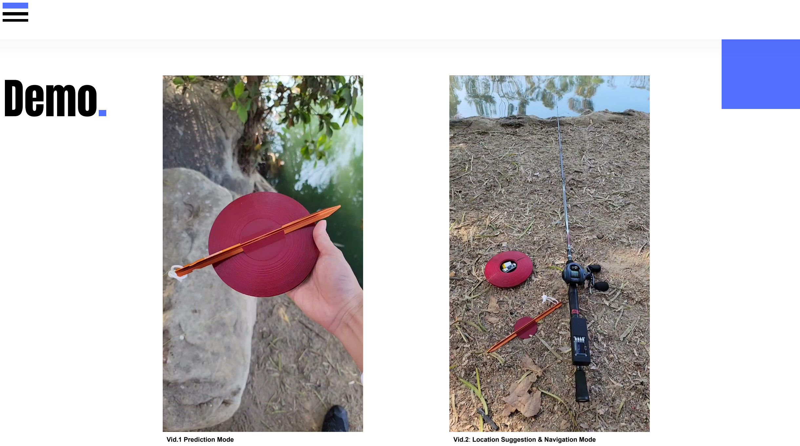
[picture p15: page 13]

Vid.1 Prediction Mode | Vid.2: Location Suggestion & Navigation Mode

# Experimental Evaluation. Metrics

MSE: Evaluates the average squared error between predicted and actual values to

measure accuracy.

RMSE: Square root of MSE, providing an interpretable error in the same units as the

target variable.

Relative Error: Measures the difference between testing and training MSE as a

percentage of the training MSE.

Prediction Speed: Measure the time taken for the system to compute a prediction.

Power Efficiency: Evaluate the system's energy consumption during operation.

- Average power consumption (mW).
- Battery life (hours) on a given power source.

# Experimental Evaluation. Results

Testing MSE: 0.2498 | Training MSE: 0.2751
Testing RMSE: 0.4998 | Training RMSE: 0.5245

Relative Error: 10.12% (Training MSE: 0.2751 vs. Testing MSE: 0.2498)

Average Prediction Speed: 15 ms

Central Device Power Efficiency:

- Average power consumption 408.6 mW.
- Battery life 4.77 hours.

Memory use: 90%

Peripheral Device Power Efficiency:

- Average power consumption 70.2mW.
- Battery life 27.76 hours.

Memory use: 23%

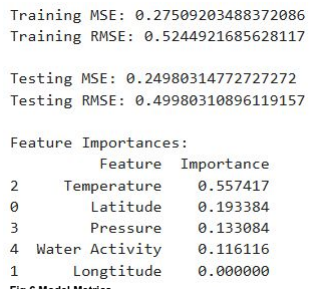
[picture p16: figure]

Fig.6 Model Metrics

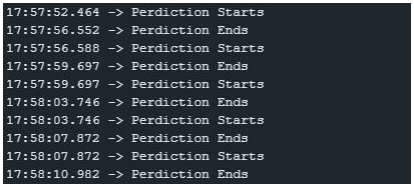
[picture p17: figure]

Fig.7 Serial Monitor output of prediction time

# Experimental Evaluation. Finding

Beginners without any experiences:

- Show a higher level of dependence on the system and use it more frequently.
- Their actual catch rates are generally lower than the system's predictions due to lack of experience.
- Rely heavily on fishing location recommendations for guidance.

Intermediate and Advanced Users:

- Use the system less frequently but demonstrate higher alignment between their catch rates and the system's predictions.
- Depend more on fish activity predictions to refine their strategies.

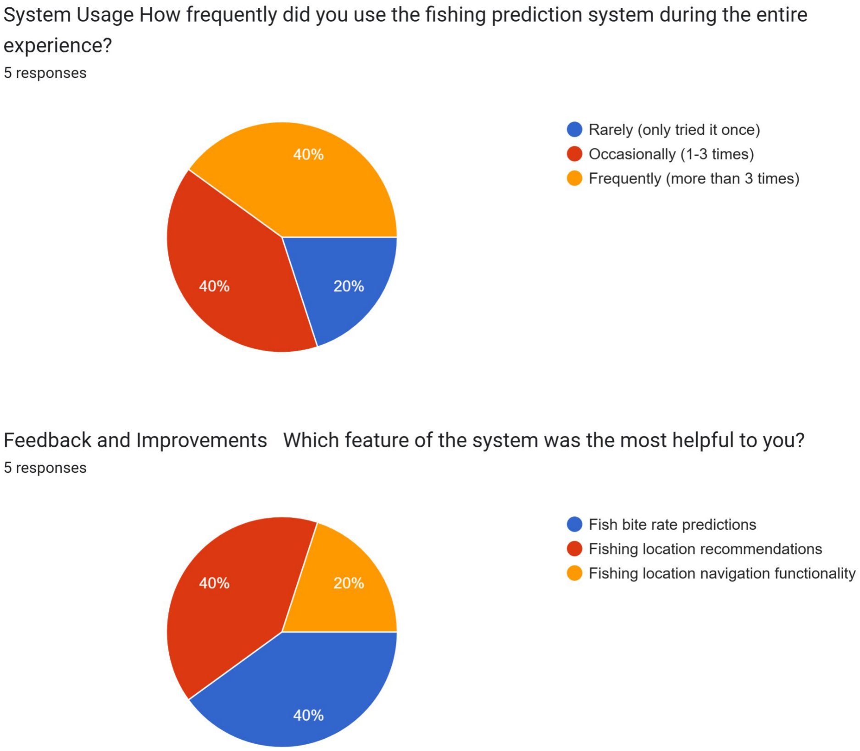
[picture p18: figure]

Fig.8 Example of User Study Results

Conclusions.

- The system helps both beginners and experienced users by providing

useful fishing predictions.

- Beginners benefit the most from location recommendations and use the

system more frequently.

- Experienced users use the system less often but rely more on fish activity

predictions to improve their results.

- The decision tree model works well, with a low testing error and accurate predictions in different conditions.
- The system’s real-time predictions and low power use make it reliable for long fishing trips.
- User feedback shows the system is easy to use and helpful, with 80% of users willing to recommend it to others.

Discussions.

Hardware Improvements:

- Replace the current GPS module with an Adafruit GPS module for lower power consumption and support for low-power modes.
- Optimize the device enclosure to make it more compact and portable, improving user convenience.

Data Collection:

- Expand data collection to include more sessions and diverse water bodies, improving model accuracy and supporting more fishing

conditions.

Future Features:

- Include measurements like water depth or dissolved oxygen to improve prediction accuracy.
- 加上能让用户设定自己的水平，系统可以根据用户的设定scale最终的预测结果

Question & Answer .

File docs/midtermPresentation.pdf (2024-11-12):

# Aquatic Catch

Predictor.

## Zixuan Yang

Motivation and Objectives.

Develop a portable device to predict fish activity and suggest optimal fishing spots.

Simplify and enhance the fishing experience using data-driven insights.

Who cares? Why does it matter?

- Recreational and competitive anglers seeking to improve their skills and catch rates.
- Saves time and resources, leading to a better fishing experience.

Goals and Deliverables:

- Design a low-power, user-friendly prediction system integrating weather, GPS, and sensors.
- Deliver a working prototype with an evaluation report demonstrating prediction accuracy and user impact.

Technical Approach and Novelty.

Limitations of current fishing forecast application:

- Current systems primarily rely on traditional knowledge and weather forecasts (No data-backed evidence).
- Often require a smartphone and internet connectivity, limiting their usability in remote fishing locations.

Approach:

- Integrate real-time weather data from environmental sensors(temperature, pressure and water activity), GPS.
- Use machine learning model (classification) to predict fishing success.
- Low power consumption and more accessible(no internet needed).

What's New:

- Real-time Data Integration: Combines multiple environmental factors for accurate predictions.
- Data-Driven Fishing Recommendations: Utilizes classification techniques to guide anglers.

Methods.

Data Collection:

- Three people with different skill level to collect data (fish bites/half hour).
- Collectors exchange location every 10 minutes, each test point includes data from each collector (objective).

Platforms:

- Arduino Nano 33 BLE (Water Beacon)
- ESP-WROOM-32 (User end device)
- Arduino IDE (MCU), Python (Decision tree)

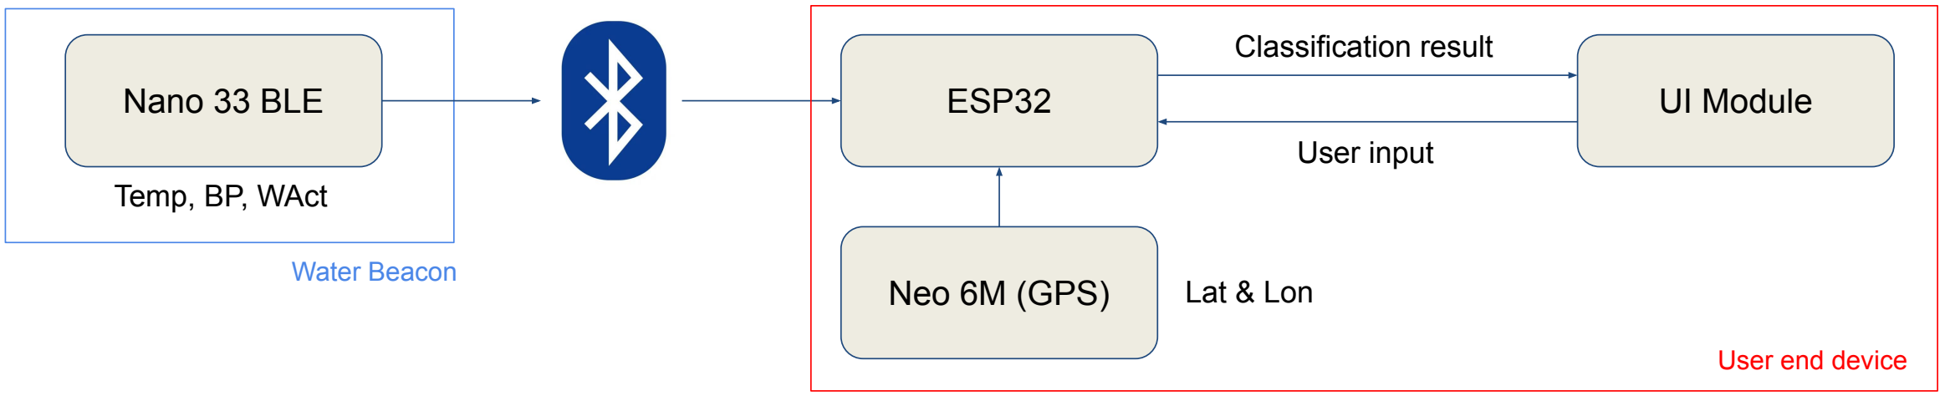
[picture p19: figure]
Nano 33 BLE; ESP32; Neo 6M (GPS); UI Module; Temp, BP, WAct; User end device; Water Beacon; Lat & Lon; Classification result; User input

Evaluation and Metrics.

Prediction Accuracy:

- Use Mean Squared Error (MSE) to measure the accuracy of the regression model’s predictions for fish activity.

Fishing Success Rate:

- Compare the number of fish caught when users follow the device’s recommendations versus traditional fishing methods (e.g., trial and

error or experience-based decisions).

- Conduct controlled experiments by dividing participants into two groups:
- Group A uses the device.
- Group B uses traditional methods.
- Record metrics such as:
- Average catch per hour.
- Time taken to catch the first fish.
- Overall satisfaction with the fishing experience.

Current Status and Next Steps.

Current:

- 90 data points are collected (18 data points left)
- Water beacon finished, used in data collection
- Prototype user end device is built and tested

Future:

- Develop a 3D model for the user-end device that can be easily installed on a variety of fishing rods, ensuring compatibility and

convenience for users.

- Finalize the remaining 18 data points to ensure a robust and comprehensive dataset for model training.
- Train the decision tree model using the collected dataset and implement the optimized algorithm on the user-end device for real-time

predictions.

- Conduct thorough tests to evaluate the device’s performance.
- Compare the results with traditional fishing methods, focusing on metrics like fishing success rate and user satisfaction to validate

the device’s effectiveness.

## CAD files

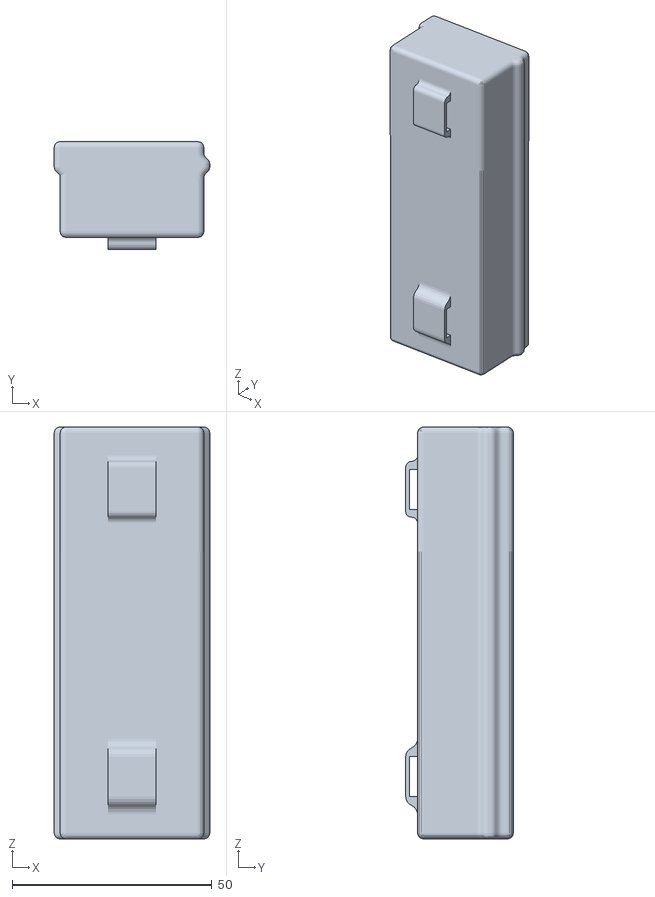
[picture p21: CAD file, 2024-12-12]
hardware/central_device_demo.stl
39.0 x 27.0 x 103.2

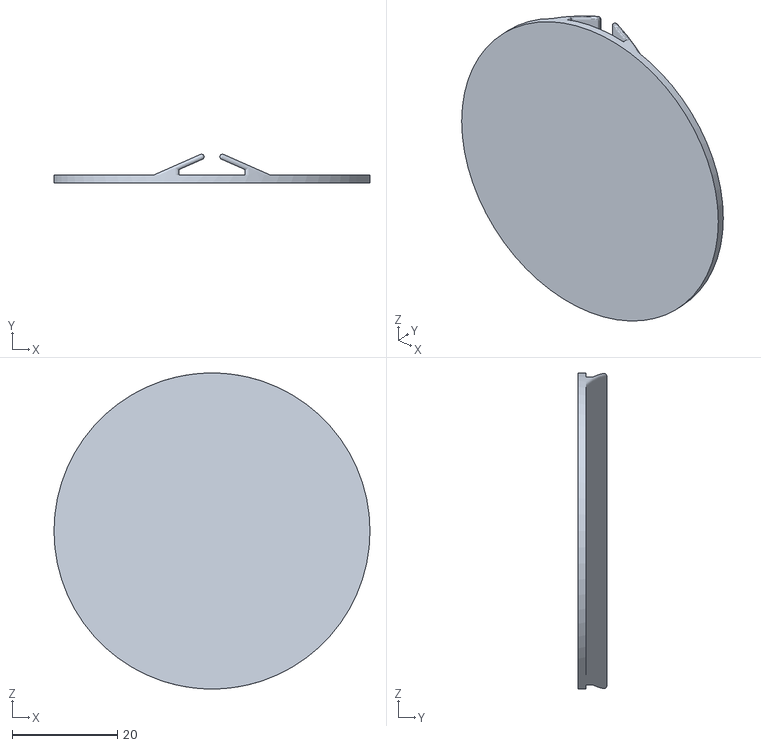
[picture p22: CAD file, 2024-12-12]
hardware/peripheralB.stl
60.0 x 5.45 x 60.0

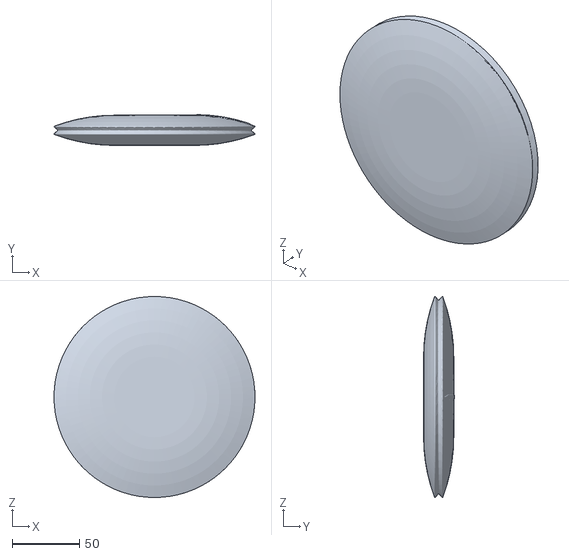
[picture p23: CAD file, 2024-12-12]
hardware/peripheralA.stl
149.7 x 23.0 x 149.7

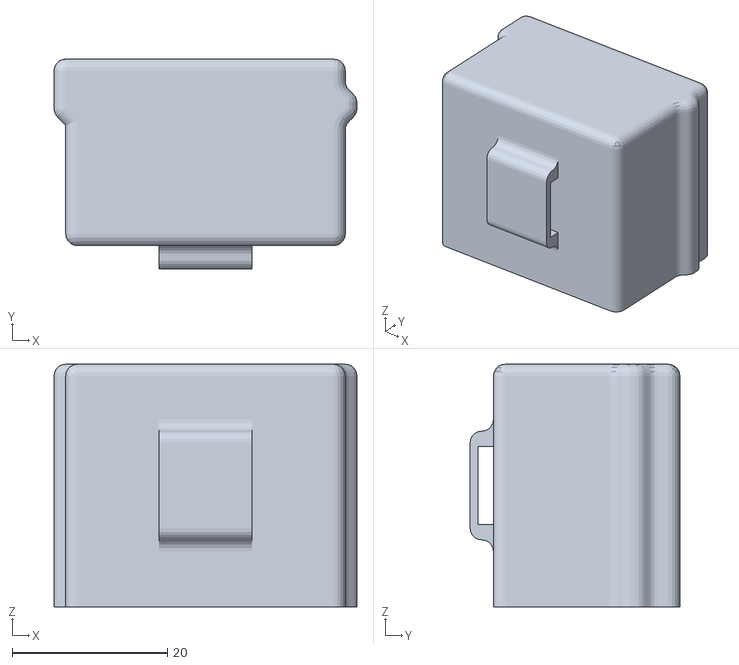
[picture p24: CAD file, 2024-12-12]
hardware/centralA.stl
39.0 x 27.0 x 31.2

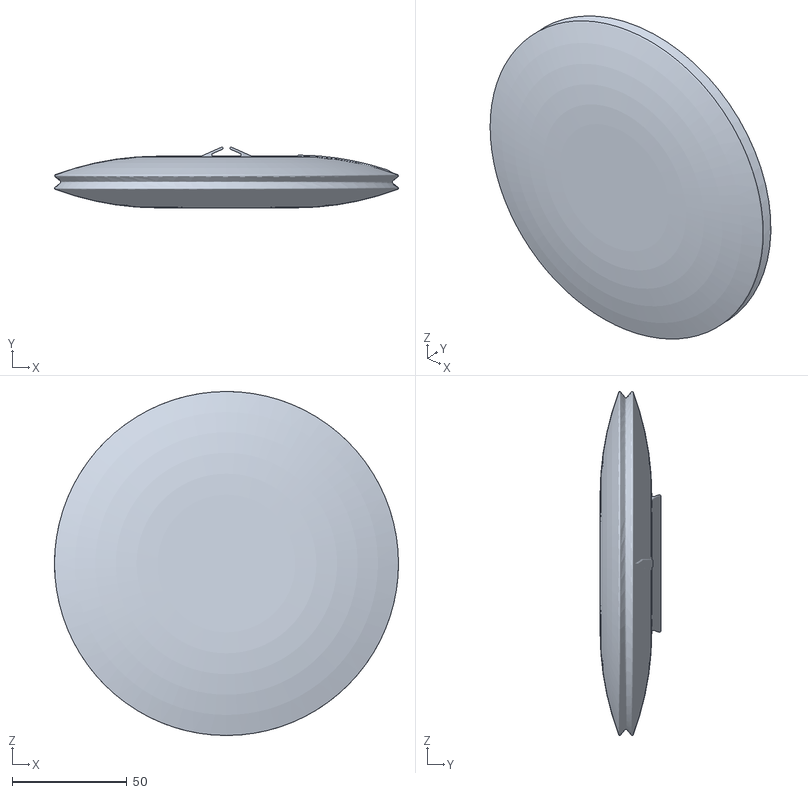
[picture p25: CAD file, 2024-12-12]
hardware/peripheral_demo.stl
149.7 x 26.5 x 149.7

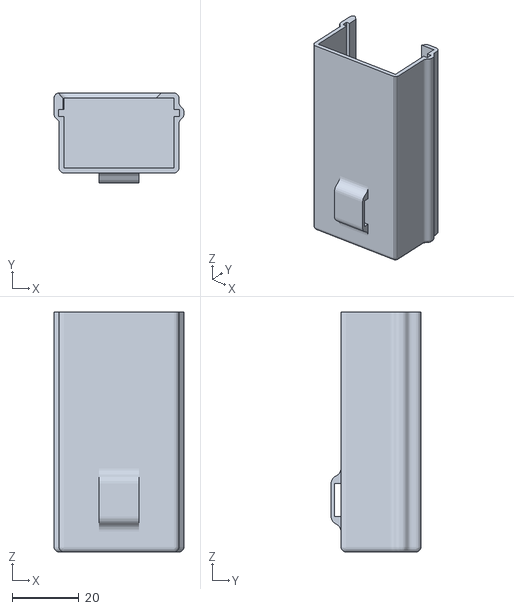
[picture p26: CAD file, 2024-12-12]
hardware/centralB.stl
39.0 x 27.0 x 72.0

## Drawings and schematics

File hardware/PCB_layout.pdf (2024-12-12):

U3

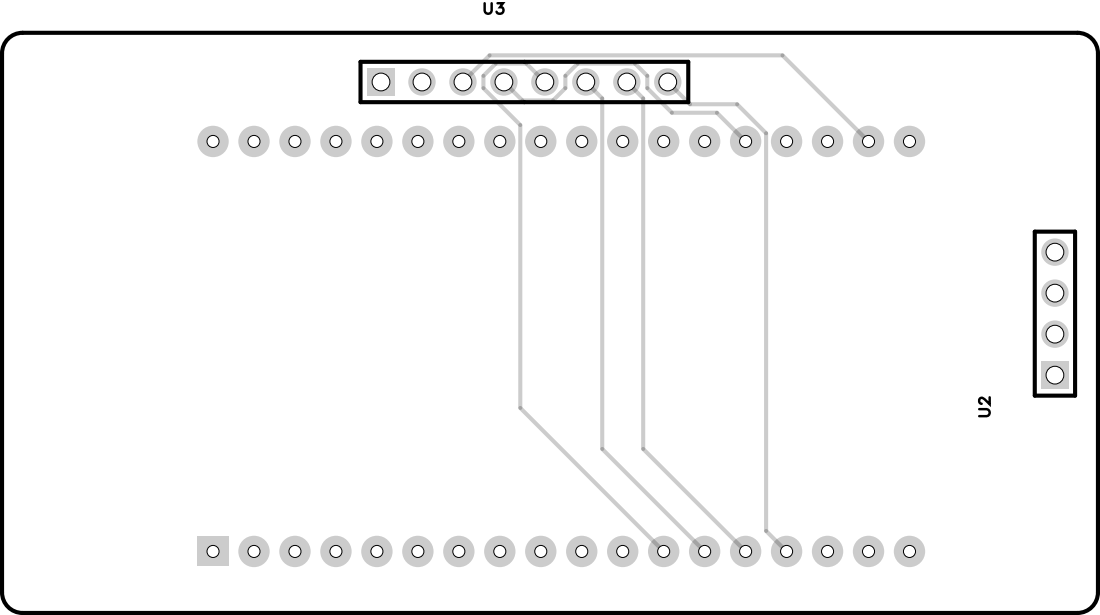
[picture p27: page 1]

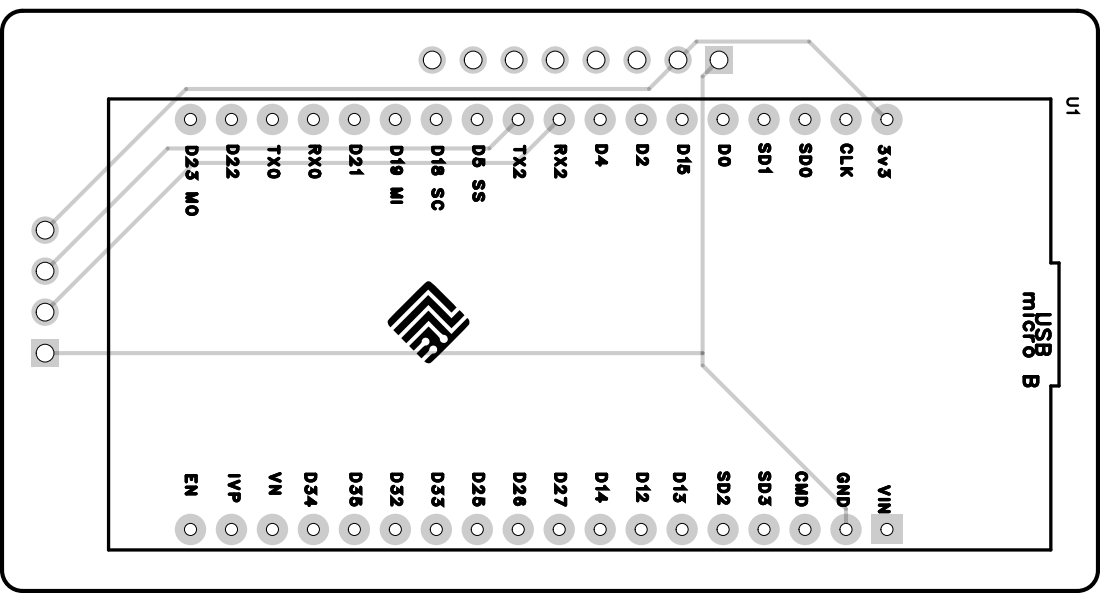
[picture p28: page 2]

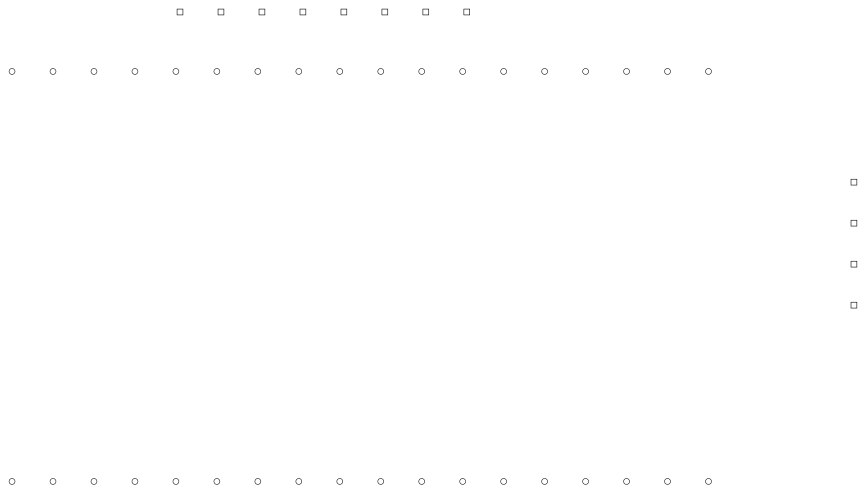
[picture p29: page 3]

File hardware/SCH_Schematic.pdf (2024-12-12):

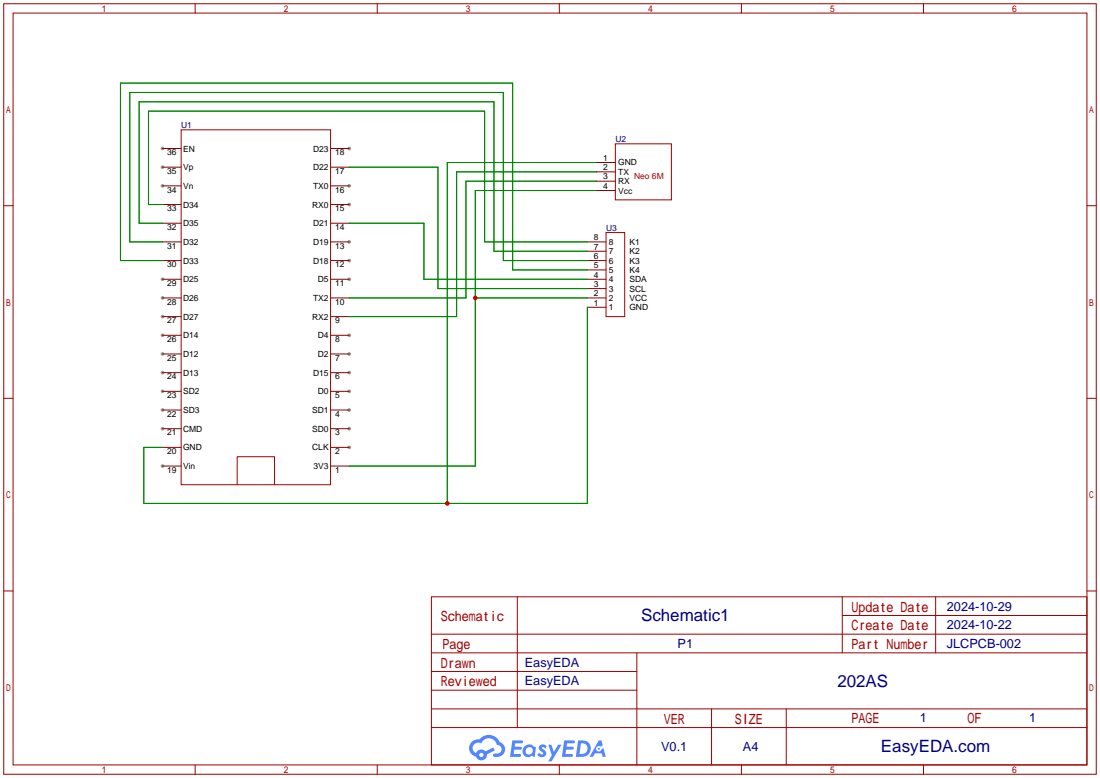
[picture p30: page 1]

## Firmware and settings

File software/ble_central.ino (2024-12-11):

#include <BLEDevice.h>
#include <BLEUtils.h>
#include <BLEScan.h>
#include <BLEClient.h>
#include <TinyGPSPlus.h>  // Include TinyGPS++ library for GPS data parsing
#include <Wire.h>
#include <Adafruit_GFX.h>
#include <Adafruit_SSD1306.h>

// OLED display configuration
#define SCREEN_WIDTH 128
#define SCREEN_HEIGHT 64
#define OLED_RESET -1
Adafruit_SSD1306 display(SCREEN_WIDTH, SCREEN_HEIGHT, &Wire, OLED_RESET);

// UUIDs for BLE services and characteristics
#define SERVICE_UUID "181A"         // Environmental Sensing Service UUID
#define TEMPERATURE_UUID "2A6E"     // UUID for temperature characteristic
#define PRESSURE_UUID "2A6D"        // UUID for pressure characteristic
#define WATER_ACTIVITY_UUID "2A6F"  // UUID for water activity characteristic
#define DIRECTION_UUID "2B0E"       // UUID for direction characteristic
#define HEADING_UUID "2B0F"         // UUID for heading (angle) characteristic

// GPS module configuration
#define RXD2 16         // GPS module RX pin
#define TXD2 17         // GPS module TX pin
#define GPS_BAUD 9600   // Baud rate for GPS module communication

// Button GPIO pin definitions
#define BUTTON_K1 34
#define BUTTON_K2 35
#define BUTTON_K3 32
#define BUTTON_K4 33

// Flags to track button presses
volatile bool buttonK1Pressed = false;
volatile bool buttonK2Pressed = false;
volatile bool buttonK3Pressed = false;
volatile bool buttonK4Pressed = false;

// Variables to store selected target location
float targetLatitude = 0.0;         // Target latitude
float targetLongitude = 0.0;        // Target longitude
float highestLocations[3][2] = {    // Array to store top 3 recommended locations
    {0.0, 0.0}, 
    {0.0, 0.0}, 
    {0.0, 0.0}
};

// BLE connection flags and device pointers
bool doConnect = false;             // Flag to initiate connection
bool connected = false;             // Connection status flag
BLEAdvertisedDevice* myDevice;      // Pointer to the discovered device
BLERemoteService* pRemoteService = nullptr; // Pointer to the remote service

// Variables for sensor data
uint16_t temperatureValue = 0;      // Temperature value
uint32_t pressureValue = 0;         // Pressure value
bool waterActivity = false;         // Water surface activity flag

// Flags to track new data availability
bool newTemperature = false;
bool newPressure = false;
bool newWaterActivity = false;
bool needsRecalculation = true;     // Flag to indicate if recalculation is needed

// GPS instance and serial configuration
TinyGPSPlus gps;                    // GPS data parser object
HardwareSerial gpsSerial(2);        // Serial port for GPS communication

// Enumeration for menu states
enum MenuState { 
    MAIN_MENU,                      // Main menu state
    FISH_PREDICT,                   // Fishing prediction menu state
    LOCATION_RECOMMEND,             // Location recommendation menu state
    NAVIGATION                      // Navigation menu state
};
MenuState currentMenuState = MAIN_MENU; // Initialize to main menu state

// BLE client callback to handle connection events
class MyClientCallback : public BLEClientCallbacks {
  void onConnect(BLEClient* pClient) {
    connected = true;
    Serial.println("Connected to peripheral device.");
  }

  void onDisconnect(BLEClient* pClient) {
    connected = false;
    Serial.println("Disconnected from peripheral device.");
  }
};

// BLE advertised device callback to handle discovered devices
class MyAdvertisedDeviceCallbacks : public BLEAdvertisedDeviceCallbacks {
  void onResult(BLEAdvertisedDevice advertisedDevice) {
    // Check if the advertised device matches the target service UUID
    if (advertisedDevice.haveServiceUUID() && advertisedDevice.isAdvertisingService(BLEUUID(SERVICE_UUID))) {
      Serial.println("Found target device, connecting...");
      myDevice = new BLEAdvertisedDevice(advertisedDevice); // Save the discovered device
      doConnect = true;                                     // Set connection flag
      BLEDevice::getScan()->stop();                        // Stop scanning upon finding the device
    }
  }
};

/**
 * @brief Connect to the BLE peripheral device.
 * This function attempts to establish a BLE connection with the target peripheral
 * and retrieves its environmental sensing service.
 */
void connectToPeripheral() {
  if (doConnect) {
    BLEClient* pClient = BLEDevice::createClient();
    pClient->setClientCallbacks(new MyClientCallback());

    // Attempt to connect to the target device
    if (pClient->connect(myDevice)) {
      Serial.println("Connected to peripheral.");

      // Retrieve the environmental sensing service
      pRemoteService = pClient->getService(BLEUUID(SERVICE_UUID));
      if (pRemoteService == nullptr) {
        Serial.println("Failed to find our service UUID.");
        pClient->disconnect();
        return;
      }
      connected = true;  // Mark connection as successful
    } else {
      Serial.println("Failed to connect to peripheral.");
      connected = false;
    }

    doConnect = false; // Reset connection request flag
  }
}

/**
 * @brief Read characteristics from the remote BLE service.
 * This function reads temperature, pressure, water activity, direction,
 * and heading values from the remote device.
 */
void readCharacteristics(BLERemoteService* pRemoteService) {
  // Read temperature characteristic
  BLERemoteCharacteristic* pTempCharacteristic = pRemoteService->getCharacteristic(BLEUUID(TEMPERATURE_UUID));
  if (pTempCharacteristic != nullptr && pTempCharacteristic->canRead()) {
    temperatureValue = pTempCharacteristic->readUInt16();
    newTemperature = true;
    //Serial.print("Temperature: ");
    //Serial.println(temperatureValue / 100.0);
  }

  // Read pressure characteristic
  BLERemoteCharacteristic* pPressureCharacteristic = pRemoteService->getCharacteristic(BLEUUID(PRESSURE_UUID));
  if (pPressureCharacteristic != nullptr && pPressureCharacteristic->canRead()) {
    pressureValue = pPressureCharacteristic->readUInt32();
    newPressure = true;
    //Serial.print("Pressure: ");
    //Serial.println(pressureValue / 100.0);
  }

  // Read water activity characteristic
  BLERemoteCharacteristic* pWaterActivityCharacteristic = pRemoteService->getCharacteristic(BLEUUID(WATER_ACTIVITY_UUID));
  if (pWaterActivityCharacteristic != nullptr && pWaterActivityCharacteristic->canRead()) {
    waterActivity = pWaterActivityCharacteristic->readUInt8();
    newWaterActivity = true;
    //Serial.print("Water Activity: ");
    //Serial.println(waterActivity ? "Active" : "Calm");
  }

  // Read direction characteristic
  BLERemoteCharacteristic* pDirectionCharacteristic = pRemoteService->getCharacteristic(BLEUUID(DIRECTION_UUID));
  if (pDirectionCharacteristic != nullptr && pDirectionCharacteristic->canRead()) {
    String direction = pDirectionCharacteristic->readValue().c_str();
    //Serial.print("Direction: ");
    //Serial.println(direction);
  } else {
    Serial.println("Direction characteristic not found or cannot read.");
  }

  // Read heading characteristic
  BLERemoteCharacteristic* pHeadingCharacteristic = pRemoteService->getCharacteristic(BLEUUID(HEADING_UUID));
  if (pHeadingCharacteristic != nullptr && pHeadingCharacteristic->canRead()) {
    uint16_t headingValue = pHeadingCharacteristic->readUInt16();  // Read as 16-bit integer
    float heading = headingValue / 100.0;                          // Convert to float
    //Serial.print("Heading (degrees): ");
    //Serial.println(heading);
  } else {
    Serial.println("Heading characteristic not found or cannot read.");
  }
}

/**
 * @brief Display the current menu on the OLED screen.
 * This function updates the OLED display with the current menu state and options.
 */
void displayMenu() {
  display.clearDisplay();
  display.setTextSize(1);
  display.setTextColor(SSD1306_WHITE);
  display.setCursor(0, 0);

  // Display menu options based on the current menu state
  switch (currentMenuState) {
    case MAIN_MENU:
      display.println("Main Menu:");
      display.println("  1. Fish Predict");
      display.println("  2. Suggest Spots");
      break;
    case FISH_PREDICT:
      display.println("Fish Prediction:");
      display.println("  Press * to return");
      break;
    case LOCATION_RECOMMEND:
      display.println("Suggest Spots:");
      display.println("  Press * to return");
      break;
  }

  display.display(); // Refresh the OLED screen
}

/**
 * @brief Calculate the predicted bite rate of fish.
 * This function uses environmental variables to estimate the fish bite rate
 * in a given location using decision tree logic.
 * 
 * @param temperature Current temperature in °C
 * @param pressure Atmospheric pressure in hPa
 * @param waterActivity Water activity indicator (0 or 1)
 * @param latitude Latitude of the location
 * @param longitude Longitude of the location
 * @return Predicted fish bite rate
 */
float calculateBiteRate(float temperature, float pressure, float waterActivity, float latitude, float longitude) {
  float fishPrediction = 0.0;

  // Decision tree logic to predict fish bite rate
  if (temperature <= 20.11) {
    if (latitude <= 34.01) {
      if (waterActivity <= 0.50) {
        fishPrediction = 2.42;
      } else {
        if (latitude <= 34.01) {
          fishPrediction = 0.00;
        } else {
          fishPrediction = 0.79;
        }
      }
    } else {
      if (pressure <= 1007.80) {
        fishPrediction = 2.00;
      } else {
        fishPrediction = 2.83;
      }
    }
  } else {
    if (pressure <= 1011.90) {
      if (temperature <= 24.20) {
        fishPrediction = 3.67;
      } else {
        if (latitude <= 34.01) {
          fishPrediction = 0.40;
        } else {
          fishPrediction = 2.33;
        }
      }
    } else {
      if (latitude <= 34.01) {
        if (waterActivity <= 0.50) {
          fishPrediction = 4.60;
        } else {
          fishPrediction = 2.84;
        }
      } else {
        fishPrediction = 4.61;
      }
    }
  }
  
  return fishPrediction;
}

/**
 * @brief Recommend fishing spots based on the bite rate.
 * This function calculates and ranks the top 3 fishing spots based on environmental
 * variables and user-selected criteria.
 * 
 * @param temperature Current temperature in °C
 * @param pressure Atmospheric pressure in hPa
 * @param waterActivity Indicator of water activity (true for active, false for calm)
 */
void recommendFishingSpots(float temperature, float pressure, bool waterActivity) {
  Serial.println("Location Rec. Starts");
  // Skip recalculation if already computed
  if (!needsRecalculation) {
    displayTop3Spots();
    return;
  }

  // Array to store the highest bite rates
  float highestBiteRates[3] = { 0.0, 0.0, 0.0 };

  // Predefined list of GPS coordinates for evaluation
  float gpsList[][2] = {
      {34.009983, -118.370949}, {34.010011, -118.370909},
      {34.010037, -118.370852}, {34.010049, -118.370787},
      {34.010047, -118.370708}, {34.010039, -118.370624},
      {34.010010, -118.370571}, {34.009972, -118.370529},
      {34.009927, -118.370498}, {34.009884, -118.370466},
      {34.009847, -118.370460}, {34.009798, -118.370453},
      {34.009757, -118.370408}, {34.009746, -118.370347},
      {34.009767, -118.370252}, {34.009626, -118.370251},
      {34.009571, -118.370226}, {34.009522, -118.370214},
      {34.009468, -118.370214}, {34.009409, -118.370226},
      {34.009338, -118.370229}, {34.009273, -118.370216},
      {34.009194, -118.370169}, {34.009132, -118.370129},
      {34.009047, -118.370118}, {34.008995, -118.370185},
      {34.008946, -118.370241}, {34.008909, -118.370585},
      {34.008935, -118.370671}, {34.008983, -118.370737},
      {34.009030, -118.370795}, {34.009069, -118.370842},
      {34.009126, -118.370894}, {34.009194, -118.370913},
      {34.009246, -118.370913}, {34.009303, -118.370910},
      {34.009351, -118.370900}
  };

  int gpsListSize = sizeof(gpsList) / sizeof(gpsList[0]);

  // Evaluate each GPS location for bite rate
  for (int i = 0; i < gpsListSize; i++) {
    float testLatitude = gpsList[i][0];
    float testLongitude = gpsList[i][1];

    // Calculate the bite rate at the given coordinates
    float biteRate = calculateBiteRate(temperature, pressure, waterActivity, testLatitude, testLongitude);

    // Update the top 3 locations if the current location is better
    for (int j = 0; j < 3; j++) {
      if (biteRate > highestBiteRates[j]) {
        // Shift lower-ranked locations down
        for (int k = 2; k > j; k--) {
          highestBiteRates[k] = highestBiteRates[k - 1];
          highestLocations[k][0] = highestLocations[k - 1][0];
          highestLocations[k][1] = highestLocations[k - 1][1];
        }
        // Update the current top location
        highestBiteRates[j] = biteRate;
        highestLocations[j][0] = testLatitude;
        highestLocations[j][1] = testLongitude;
        break;
      }
    }
  }

  // Display the menu to select one of the top spots
  display.println("Select Spot:");
  display.println("1. Spot 1");
  display.println("2. Spot 2");
  display.println("3. Spot 3");
  display.display();

  // Handle user input for selecting a spot
  if (buttonK1Pressed) {
    buttonK1Pressed = false;  // Reset flag
    targetLatitude = highestLocations[0][0];
    targetLongitude = highestLocations[0][1];
    currentMenuState = NAVIGATION; // Switch to navigation mode
  } else if (buttonK2Pressed) {
    buttonK2Pressed = false;
    targetLatitude = highestLocations[1][0];
    targetLongitude = highestLocations[1][1];
    currentMenuState = NAVIGATION;
  } else if (buttonK3Pressed) {
    buttonK3Pressed = false;
    targetLatitude = highestLocations[2][0];
    targetLongitude = highestLocations[2][1];
    currentMenuState = NAVIGATION;
  }

  // Mark recalculation as complete and display the results
  needsRecalculation = false;
  displayTop3Spots();
  Serial.println("Location Rec. Ends");
}

/**
 * @brief Display the top 3 recommended fishing spots on the OLED screen.
 */
void displayTop3Spots() {
  display.clearDisplay();
  display.setTextSize(1);
  display.setTextColor(SSD1306_WHITE);
  display.setCursor(0, 0);
  //display.println("Location Suggested:");
  display.println("Top 3 Recommendation:");
  display.println();

  // Display each top spot with its latitude and longitude
  for (int i = 0; i < 3; i++) {
    display.print(i + 1);
    display.print(": Lat: ");
    display.print(highestLocations[i][0], 6);
    display.println(",");
    display.print("  Lon: ");
    display.println(highestLocations[i][1], 6);
  }

  //display.println("Press * to return");
  display.display();
}

/**
 * @brief Navigate to the target location.
 * Calculates the distance, direction, and turn angle to reach the target location.
 * 
 * @param currentLat Current latitude of the user
 * @param currentLon Current longitude of the user
 * @param heading Current heading direction of the user
 * @param targetLat Target latitude
 * @param targetLon Target longitude
 */
void navigateToTarget(float currentLat, float currentLon, float heading, float targetLat, float targetLon) {
  // Calculate the distance to the target
  float distance = TinyGPSPlus::distanceBetween(currentLat, currentLon, targetLat, targetLon);

  // Calculate the angle to the target
  float angleToTarget = TinyGPSPlus::courseTo(currentLat, currentLon, targetLat, targetLon);

  // Print current and target coordinates for debugging
  Serial.print("Current Location: Lat = ");
  Serial.print(currentLat, 6);
  Serial.print(", Lon = ");
  Serial.println(currentLon, 6);

  Serial.print("Target Location: Lat = ");
  Serial.print(targetLatitude, 6);
  Serial.print(", Lon = ");
  Serial.println(targetLongitude, 6);

  // Calculate the relative direction to turn
  float relativeHeading = angleToTarget - heading;
  if (relativeHeading < 0) relativeHeading += 360.0;
  if (relativeHeading > 360.0) relativeHeading -= 360.0;

  // Clear the display and show navigation information
  display.clearDisplay();
  display.setTextSize(1);
  display.setTextColor(SSD1306_WHITE);
  display.setCursor(0, 0);
  display.println("Navigation Info:");
  display.println();
  display.print("Target Dis: ");
  display.print(distance, 2);
  display.println(" m");

  display.print("Target Dir: ");
  display.print(angleToTarget, 2);
  display.println(" de");
  display.println();

  display.print("Cur Dir: ");
  display.print(heading, 2);
  display.println(" deg");

  display.print("Turn ");
  if (relativeHeading < 180) {
    display.print("Right ");
    display.print(relativeHeading, 2);
    display.println(" deg");
  } else {
    display.print("Left ");
    display.print(360 - relativeHeading, 2);
    display.println(" deg");
  }

  //display.println("Press * to return");
  display.display();
}

/**
 * @brief Interrupt handler for Button K1.
 */
void IRAM_ATTR handleButtonK1() {
  buttonK1Pressed = true;
}

/**
 * @brief Interrupt handler for Button K2.
 */
void IRAM_ATTR handleButtonK2() {
  buttonK2Pressed = true;
}

/**
 * @brief Interrupt handler for Button K3.
 */
void IRAM_ATTR handleButtonK3() {
  buttonK3Pressed = true;
}
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
void loop() {
  // Check for GPS data and decode it
  while (gpsSerial.available() > 0) {
    gps.encode(gpsSerial.read());
  }

  // Handle the main menu
  if (currentMenuState == MAIN_MENU) {
    if (buttonK1Pressed) {
      buttonK1Pressed = false; // Reset flag
      currentMenuState = FISH_PREDICT; // Switch to fish prediction menu
      displayMenu();
    } else if (buttonK2Pressed) {
      buttonK2Pressed = false; // Reset flag
      currentMenuState = LOCATION_RECOMMEND; // Switch to location recommendation menu
      displayMenu();
    }
    return; // Exit to avoid executing further logic
  }

  // Handle fish prediction menu
  if (currentMenuState == FISH_PREDICT) {
    Serial.println("Perdiction Starts");
    if (connected && pRemoteService != nullptr) {
      // Read sensor characteristics
      readCharacteristics(pRemoteService);

      float temperature = temperatureValue / 100.0;
      float pressure = pressureValue / 100.0;
      float latitude = gps.location.isValid() ? gps.location.lat() : 0.0;
      float longitude = gps.location.isValid() ? gps.location.lng() : 0.0;

      // Calculate fish bite rate
      float fishPrediction = calculateBiteRate(temperature, pressure, waterActivity, latitude, longitude);

      // Display prediction on the OLED
      display.clearDisplay();
      display.setTextSize(1);
      display.setTextColor(SSD1306_WHITE);
      display.setCursor(0, 0);
      display.println("Fish Prediction:");
      display.print("Prediction: ");
      display.println(fishPrediction);
      display.println("Press * to return");
      display.display();
      Serial.println("Perdiction Ends");
    } else {
      Serial.println("Disconnected. Reconnecting...");
      connectToPeripheral();
    }

    // Return to main menu if the back button is pressed
    if (buttonK4Pressed) {
      buttonK4Pressed = false;
      currentMenuState = MAIN_MENU;
      displayMenu();
    }
    return;
  }

  // Handle location recommendation menu
  if (currentMenuState == LOCATION_RECOMMEND) {
    if (needsRecalculation) {
      // Recalculate top fishing spots
      float temperature = temperatureValue / 100.0;
      float pressure = pressureValue / 100.0;
      recommendFishingSpots(temperature, pressure, waterActivity);
      needsRecalculation = false;
    } else {
      // Display pre-calculated spots
      displayTop3Spots();
    }

    // Handle navigation button logic
    if (buttonK1Pressed) {
      buttonK1Pressed = false; // Reset flag
      targetLatitude = highestLocations[0][0];
      targetLongitude = highestLocations[0][1];
      currentMenuState = NAVIGATION; // Switch to navigation menu
      displayMenu();
    } else if (buttonK2Pressed) {
      buttonK2Pressed = false; // Reset flag
      targetLatitude = highestLocations[1][0];
      targetLongitude = highestLocations[1][1];
      currentMenuState = NAVIGATION;
      displayMenu();
    } else if (buttonK3Pressed) {
      buttonK3Pressed = false; // Reset flag
      targetLatitude = highestLocations[2][0];
      targetLongitude = highestLocations[2][1];
      currentMenuState = NAVIGATION;
      displayMenu();
    }

    // Return to main menu if the back button is pressed
    if (buttonK4Pressed) {
      buttonK4Pressed = false;
      currentMenuState = MAIN_MENU;
      needsRecalculation = true; // Mark for recalculation
      displayMenu();
    }
    return;
  }

  // Handle navigation menu
  if (currentMenuState == NAVIGATION) {
    // Get the current location from GPS
    float currentLat = gps.location.isValid() ? gps.location.lat() : 0.0;
    float currentLon = gps.location.isValid() ? gps.location.lng() : 0.0;
    uint16_t headingValue = 0;

    // Read heading direction from BLE
    if (connected && pRemoteService != nullptr) {
      BLERemoteCharacteristic* pHeadingCharacteristic = pRemoteService->getCharacteristic(BLEUUID(HEADING_UUID));
      if (pHeadingCharacteristic != nullptr && pHeadingCharacteristic->canRead()) {
        headingValue = pHeadingCharacteristic->readUInt16();
      }
    }
    float heading = headingValue / 100.0; // Convert to float

    // Display navigation information
    navigateToTarget(currentLat, currentLon, heading, targetLatitude, targetLongitude);

    // Return to main menu if the back button is pressed
    if (buttonK4Pressed) {
      buttonK4Pressed = false;
      currentMenuState = MAIN_MENU;
      needsRecalculation = true; // Mark for recalculation
      displayMenu();
    }
    return;
  }
}

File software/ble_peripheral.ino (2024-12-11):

#include <ArduinoBLE.h>
#include <Arduino_LPS22HB.h>  // Library for the LPS22HB pressure sensor
#include <Arduino_LSM9DS1.h>  // Library for the LSM9DS1 IMU sensor

// Define standard environmental sensing service UUID and characteristics UUIDs
BLEService environmentalService("181A");  // Environmental Sensing Service UUID
BLECharacteristic temperatureCharacteristic("2A6E", BLERead | BLENotify, sizeof(int16_t)); // Temperature characteristic
BLECharacteristic pressureCharacteristic("2A6D", BLERead | BLENotify, sizeof(uint32_t));   // Pressure characteristic
BLECharacteristic waterActivityCharacteristic("2A6F", BLERead | BLENotify, sizeof(uint8_t)); // Water activity characteristic

// Variables for water activity detection
float z_prev = 0.0;   // Previous z-axis acceleration
float threshold = 0.1; // Threshold for detecting activity based on acceleration change
bool is_active = false; // Flag to indicate water surface activity

void setup() {
  Serial.begin(9600);
  while (!Serial);

  // Initialize BLE
  if (!BLE.begin()) {
    Serial.println("Failed to start BLE!");
    while (1);
  }

  // Initialize pressure sensor
  if (!BARO.begin()) {
    Serial.println("Failed to initialize the barometric sensor!");
    while (1);
  }

  // Initialize IMU sensor
  if (!IMU.begin()) {
    Serial.println("Failed to initialize the IMU sensor!");
    while (1);
  }

  // Set device name and add the environmental sensing service
  BLE.setLocalName("EnvSensor");
  BLE.setAdvertisedService(environmentalService);

  // Add characteristics to the service
  environmentalService.addCharacteristic(temperatureCharacteristic);
  environmentalService.addCharacteristic(pressureCharacteristic);
  environmentalService.addCharacteristic(waterActivityCharacteristic);
  BLE.addService(environmentalService);

  // Start BLE advertising
  BLE.advertise();
  Serial.println("BLE peripheral started, waiting for connections...");
}

void loop() {
  // Wait for a central device to connect
  BLEDevice central = BLE.central();

  if (central) {
    Serial.print("Connected to central device: ");
    Serial.println(central.address());

    // Maintain connection while the central device is connected
    while (central.connected()) {
      // Read temperature and pressure from the barometric sensor
      float temperature = BARO.readTemperature(); // Temperature in Celsius
      float pressure = BARO.readPressure();       // Pressure in kPa

      // Convert data to integers for BLE transmission
      int16_t temperatureValue = temperature * 100; // Convert to integer, preserving two decimals
      uint32_t pressureValue = pressure * 100;      // Convert to integer, preserving two decimals

      // Write the values to the BLE characteristics
      temperatureCharacteristic.writeValue(temperatureValue);
      pressureCharacteristic.writeValue(pressureValue);

      // Check for new acceleration data from the IMU
      float x, y, z;
      if (IMU.accelerationAvailable()) {
        IMU.readAcceleration(x, y, z); // Read acceleration data

        // Calculate the change in z-axis acceleration
        float delta_z = abs(z - z_prev);

        // Determine if the activity threshold is exceeded
        if (delta_z > threshold) {
          is_active = true;
        } else {
          is_active = false;
        }

        // Write the water activity status to the BLE characteristic
        uint8_t is_active_value = is_active ? 1 : 0;
        waterActivityCharacteristic.writeValue(is_active_value);

        // Output water activity status to the Serial Monitor
        if (is_active) {
          Serial.println("Water surface is active.");
        } else {
          Serial.println("Water surface is calm.");
        }

        // Update the previous z-axis acceleration value
        z_prev = z;
      }

      // Output temperature and pressure to the Serial Monitor
      Serial.print("Sent temperature: ");
      Serial.print(temperature);
      Serial.println(" °C");

      Serial.print("Sent pressure: ");
      Serial.print(pressure);
      Serial.println(" kPa");

      // Keep the BLE connection alive
      BLE.poll();

      // Delay to update data once per second
      delay(1000);
    }

    // Central device disconnected
    Serial.println("Central device disconnected.");
  } else {
    // No connection, add delay to reduce power consumption
    delay(1000);
  }
}
